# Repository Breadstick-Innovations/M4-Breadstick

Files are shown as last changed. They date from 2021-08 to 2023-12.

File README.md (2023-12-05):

# M4-Breadstick(retired) → [Raspberry Breadstick](https://github.com/Breadstick-Innovations/Raspberry-Breadstick)

## [Raspberry Breadstick Crowd Supply Campaign](https://www.crowdsupply.com/breadstick-innovations/raspberry-breadstick)
Be sure to [Subscribe!](https://www.crowdsupply.com/breadstick-innovations/raspberry-breadstick)

## [Hackaday IO](https://hackaday.io/project/180819-m4-breadstick)

## Adafruit Attribution
The M4-Breadstick is an adaptation of Adafruit's ItsyBitsy M4 Express; details about their board can be found [here](https://github.com/adafruit/Adafruit-ItsyBitsy-M4-Express-PCB).

## Design
### Goal
* Adapt a modern development board to a form factor which better compliments breadboard prototyping by reducing the number, length, and crossing of jumper-wires.

<insert more about the design shape and potential use cases>

### Examples
* Blink
  * [Files](Examples/1.%20Blink)
  * [YouTube Video](https://www.youtube.com/watch?v=jlcFvwoJDTA&list=PLvRCEIc8WROOZ6hJWuxPTIbie-fAAK2j3)
  
M4-Breadstick Blink Demo (https://www.youtube.com/watch?v=jlcFvwoJDTA&list=PLvRCEIc8WROOZ6hJWuxPTIbie-fAAK2j3)

* Buttons
  * [Files](Examples/7.%20Many%20Buttons)
  * [YouTube Video](https://www.youtube.com/watch?v=LMG715chEnE&list=PLvRCEIc8WROOZ6hJWuxPTIbie-fAAK2j3&index=6)
  
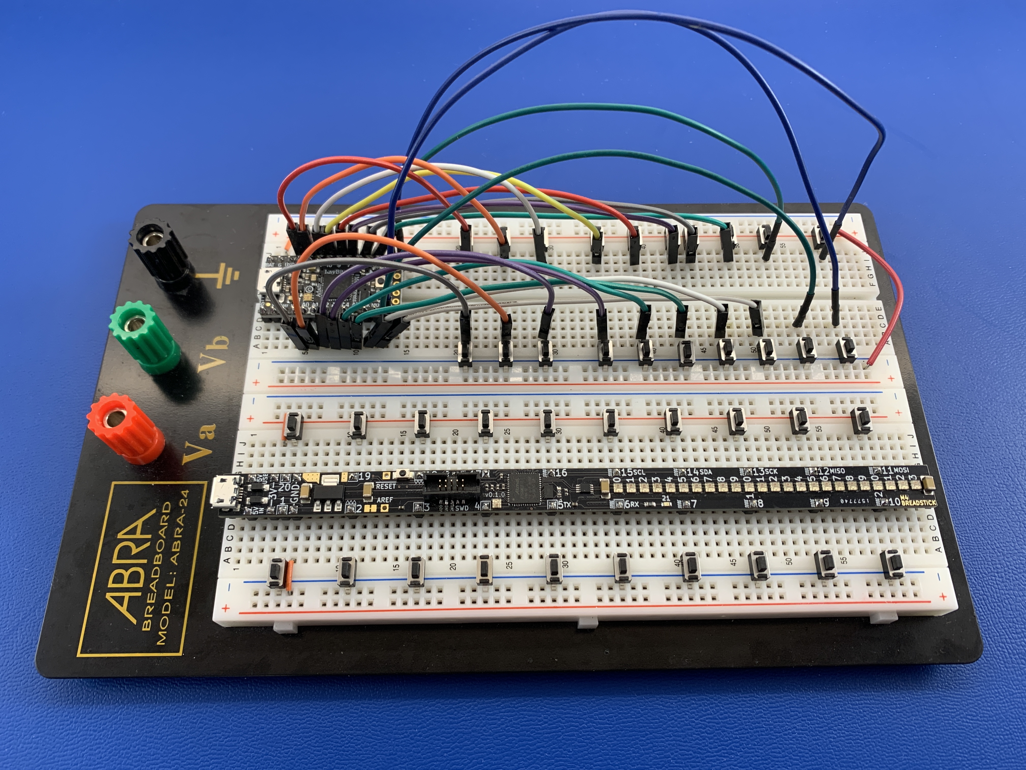
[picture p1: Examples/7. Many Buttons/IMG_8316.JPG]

M4-Breadstick Button Demo (https://www.youtube.com/watch?v=j13e2EzxIbE&list=PLvRCEIc8WROOZ6hJWuxPTIbie-fAAK2j3&index=4)
M4-Breadstick Many Buttons Demo (https://www.youtube.com/watch?v=LMG715chEnE&list=PLvRCEIc8WROOZ6hJWuxPTIbie-fAAK2j3&index=6)

* Potentiometers
  * [Files](Examples/3.%20Potentiometer/)
  * [YouTube Video](https://www.youtube.com/watch?v=UZgDf5CVg4E&list=PLvRCEIc8WROOZ6hJWuxPTIbie-fAAK2j3&index=3)
 
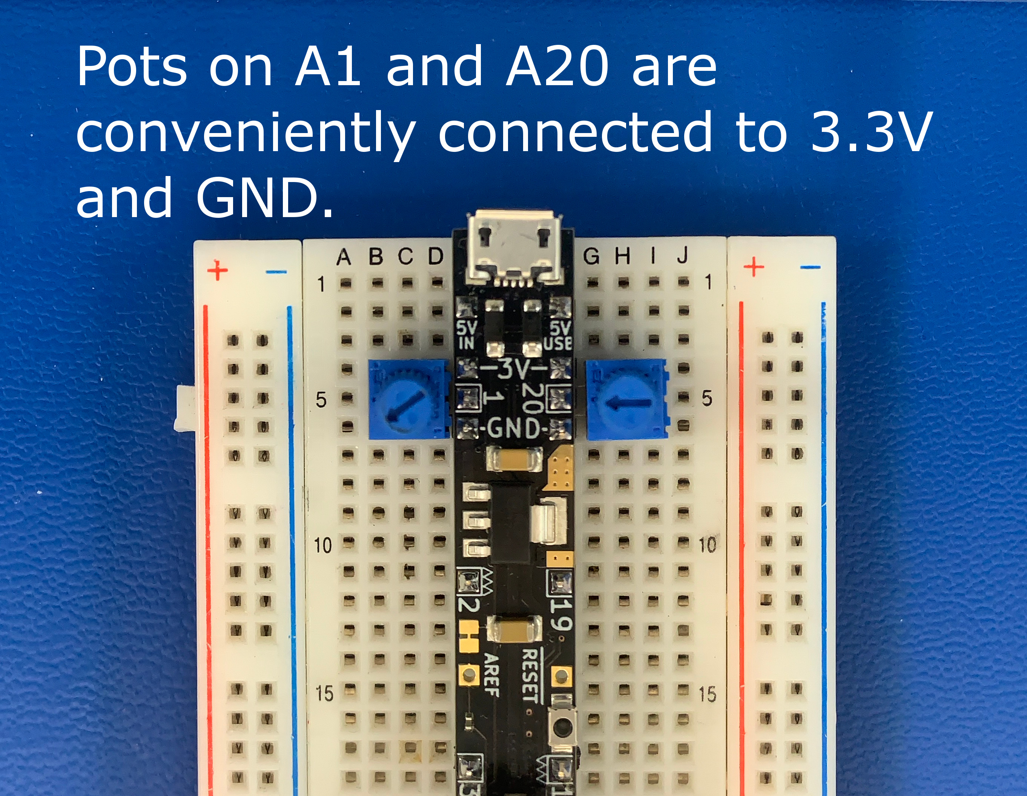
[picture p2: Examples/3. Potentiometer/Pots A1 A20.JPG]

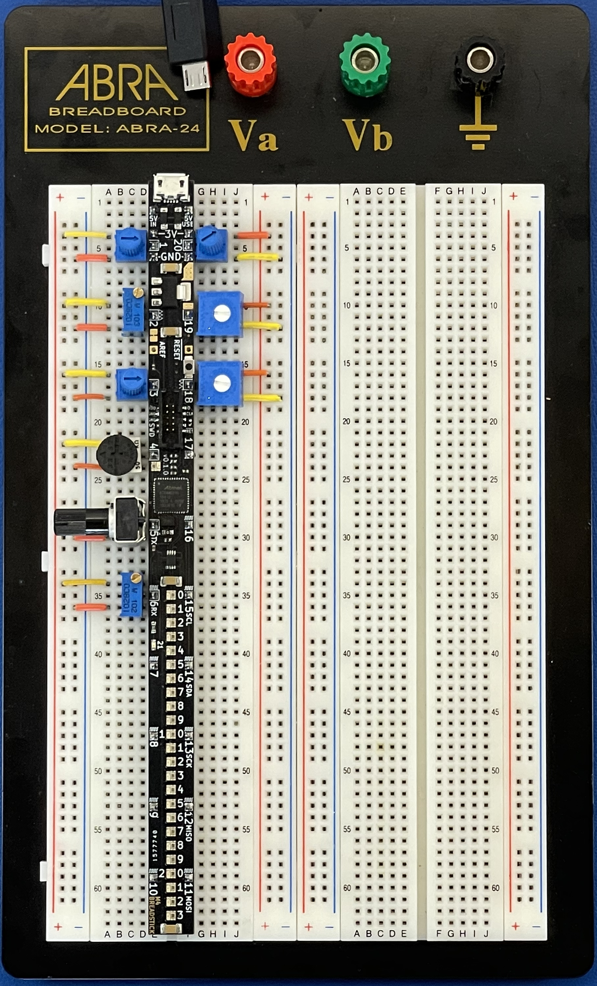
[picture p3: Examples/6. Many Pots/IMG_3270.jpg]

M4-Breadstick Potentiometer and Bar-Graph Demo (https://www.youtube.com/watch?v=UZgDf5CVg4E&list=PLvRCEIc8WROOZ6hJWuxPTIbie-fAAK2j3&index=3)

* Dual I2C Display
  * [Files](Examples/5.%20Dual%20I2C%20Display/)
  * [YouTube Video](https://www.youtube.com/watch?v=ZbwT2mgDPAQ&list=PLvRCEIc8WROOZ6hJWuxPTIbie-fAAK2j3&index=5)


M4-Breadstick Dual I2C Demo (https://www.youtube.com/watch?v=ZbwT2mgDPAQ&list=PLvRCEIc8WROOZ6hJWuxPTIbie-fAAK2j3&index=5)

* 24 Adressable RGB LED Strip (Dot-Star Compatible)
  * [Files](Examples/2.%20LED%20Strip)
  * [YouTube Video](https://www.youtube.com/watch?v=AKLR_5SblVk&list=PLvRCEIc8WROOZ6hJWuxPTIbie-fAAK2j3&index=2)

M4-Breadstick Dot-Star Compatible (Clock+Data) RGB LED Strip Demo (https://www.youtube.com/watch?v=AKLR_5SblVk&list=PLvRCEIc8WROOZ6hJWuxPTIbie-fAAK2j3&index=2)

* Motor Driver Demo
  * [Files](Examples/8.%20Motor%20Driver)
  * [YouTube Video](https://www.youtube.com/watch?v=vfRkdXOv09Y&list=PLvRCEIc8WROOZ6hJWuxPTIbie-fAAK2j3&index=7)

M4-Breadstick Motor Driver Demo (https://www.youtube.com/watch?v=vfRkdXOv09Y&list=PLvRCEIc8WROOZ6hJWuxPTIbie-fAAK2j3&index=7)

## Adafruit ItsyBitsy M4 Express PCB

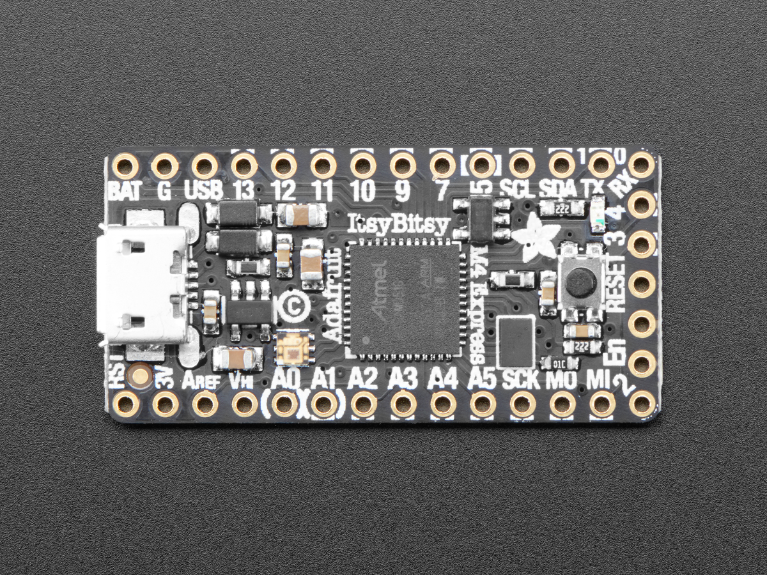
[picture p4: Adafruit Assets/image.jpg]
<a href="http://www.adafruit.com/products/3800"><br/>
Click here to purchase one from the Adafruit shop</a>

PCB files for the Adafruit ItsyBitsy M4 Express. PCB format is EagleCAD schematic and board layout

For more details, check out the product pages at
* https://www.adafruit.com/products/3800

### Description

What's smaller than a Feather but larger than a Trinket? It's an Adafruit ItsyBitsy M4 Express featuring the Microchip ATSAMD51! Small, powerful, with a ultra fast ATSAMD51 Cortex M4 processor running at 120 MHz - this microcontroller board is perfect when you want something very compact, with a ton of horsepower and a bunch of pins. This Itsy is like a bullet train, with it's 120MHz Cortex M4 with floating point support and 512KB Flash and 192KB RAM. Your code will zig and zag and zoom, and with a bunch of extra peripherals for support, this will for sure be your favorite new chipset.

ItsyBitsy M4 Express is only 1.4" long by 0.7" wide, but has 6 power pins, 23 digital GPIO pins (7 of which can be analog in, 2 x 1 MSPS analog out DACs, and 18 x PWM out). It's the same chip as the Adafruit Metro M4 but really really small. So it's great once you've finished up a prototype on a Metro M4 or (the upcoming) Feather M4, and want to make the project much smaller. It even comes with 2MB of SPI Flash built in, for data logging, file storage, or CircuitPython code.

The most exciting part of the ItsyBitsy M4 is that while you can use it with the Arduino IDE, we are shipping it with CircuitPython on board. When you plug it in, it will show up as a very small disk drive with main.py on it. Edit main.py with your favorite text editor to build your project using Python, the most popular programming language. No installs, IDE or compiler needed, so you can use it on any computer, even ChromeBooks or computers you can't install software on. When you're done, unplug the Itsy' and your code will go with you.

### License

Adafruit invests time and resources providing this open source design, please support Adafruit and open-source hardware by purchasing products from [Adafruit](https://www.adafruit.com)!

Designed by Limor Fried/Ladyada for Adafruit Industries.

Creative Commons Attribution/Share-Alike, all text above must be included in any redistribution. See license.txt for additional details.

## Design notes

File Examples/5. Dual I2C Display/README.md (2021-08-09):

## Dual I2C Display
### Description
Demonstrates the use of breadboard busses to facilitate power and I2C to multiple displays. Had to modify a config file and make a custom build of circuit python to enable a second display but it worked; firmware included above.
### Pins
The silkscreen shown in the video has a flaw, the labeled I2C pins did not actually support I2C functions. SERCOMs are very versatile; however, only SERCOMs x.0 serve as SDA and only x.1 can serve as SCL.

| Breadstick Pin | Function | Peripheral | Port |
| --- | --- | --- | --- |
| D7 | SDA | SERCOM 5.0 | PA23 |
| D8 | SCL | SERCOM 5.1 | PA22 |
| D13 | SDA | SERCOM 3.0 | PA17 |
| D16 | SCL | SERCOM 3.1 | PA16 |

### Video
M4-Breadstick Dual I2C Demo (https://www.youtube.com/watch?v=ZbwT2mgDPAQ)

https://www.youtube.com/watch?v=ZbwT2mgDPAQ

## OLED Display Mod
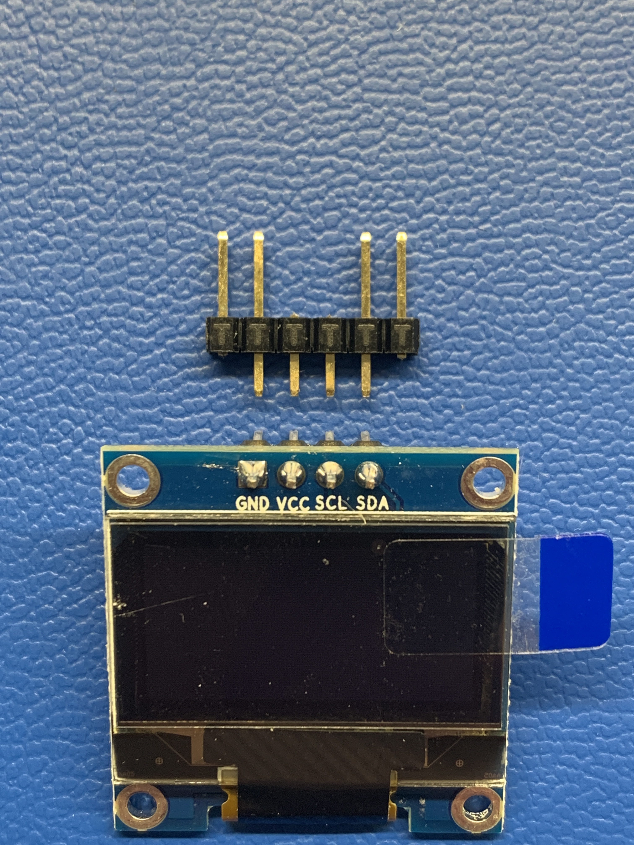
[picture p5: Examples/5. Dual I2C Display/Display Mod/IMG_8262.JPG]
<a href=""><br/>
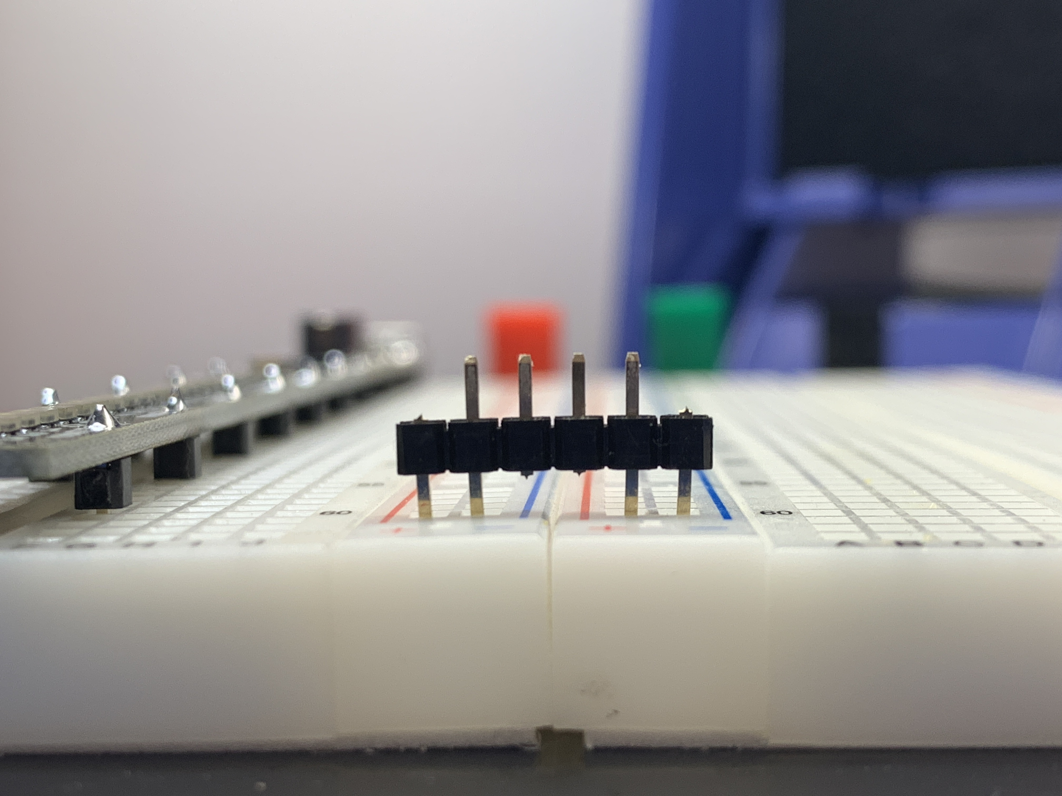
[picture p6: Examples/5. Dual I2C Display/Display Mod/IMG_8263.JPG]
<a href=""><br/>
<a href=""><br/>
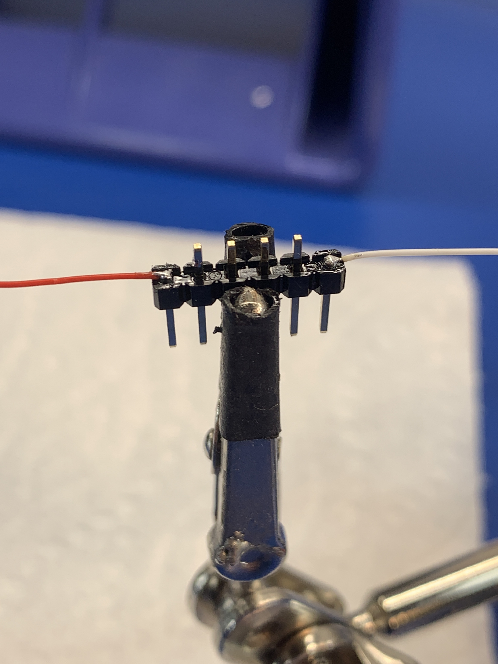
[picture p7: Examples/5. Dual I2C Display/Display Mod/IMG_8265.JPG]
<a href=""><br/>
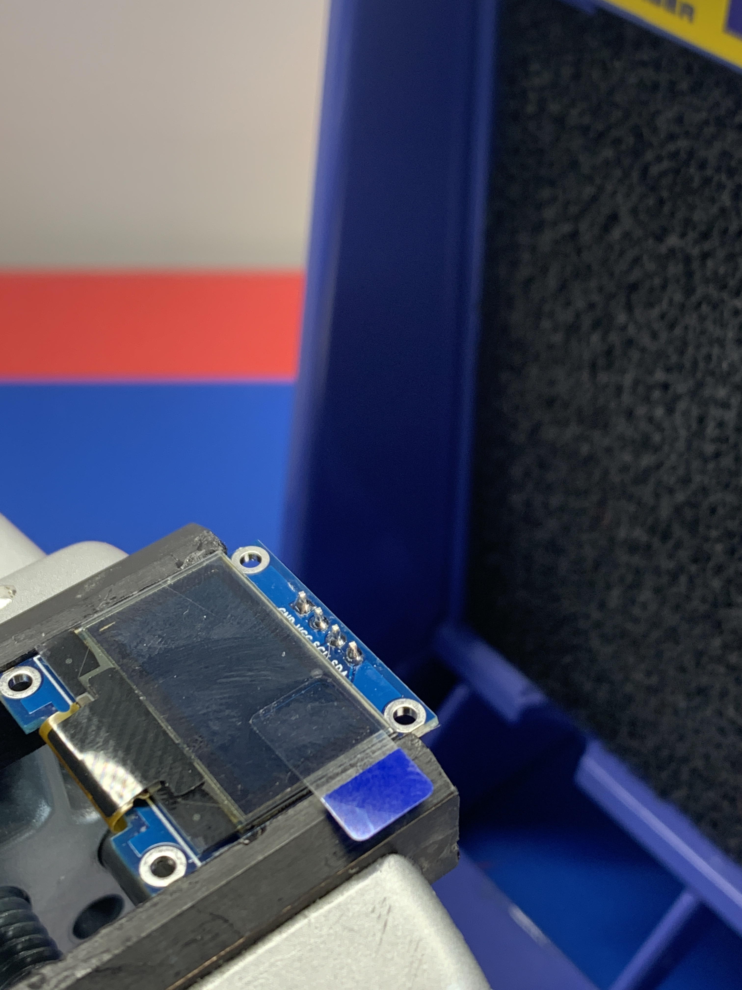
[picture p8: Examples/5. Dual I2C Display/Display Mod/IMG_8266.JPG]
<a href=""><br/>
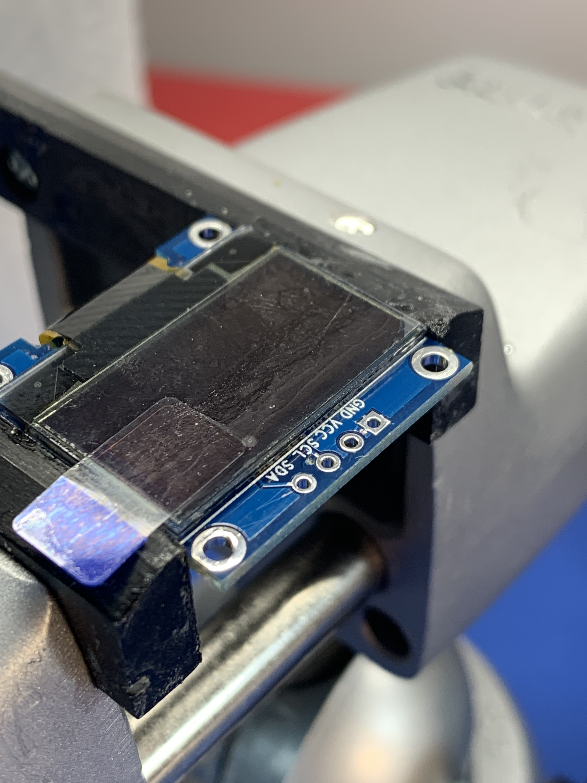
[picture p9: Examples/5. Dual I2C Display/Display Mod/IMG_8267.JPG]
<a href=""><br/>
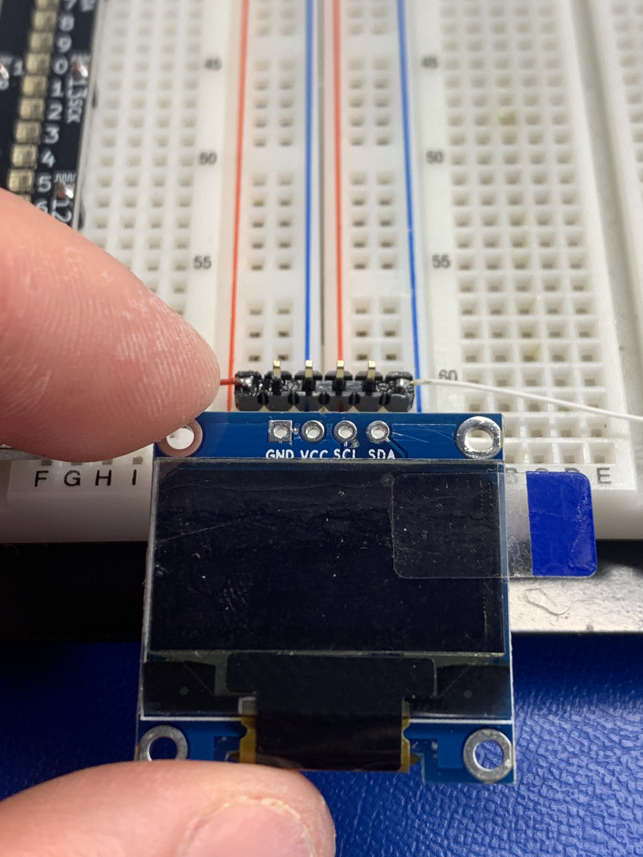
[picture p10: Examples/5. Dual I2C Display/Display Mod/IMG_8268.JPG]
<a href=""><br/>
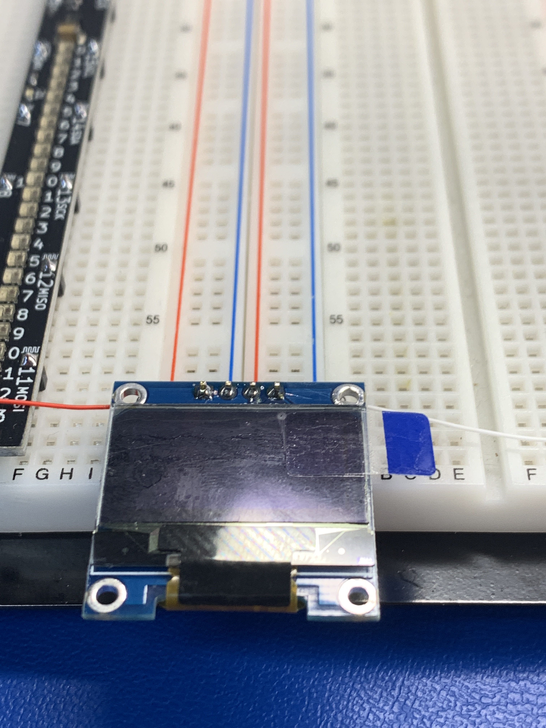
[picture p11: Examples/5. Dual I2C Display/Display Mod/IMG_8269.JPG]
<a href=""><br/>
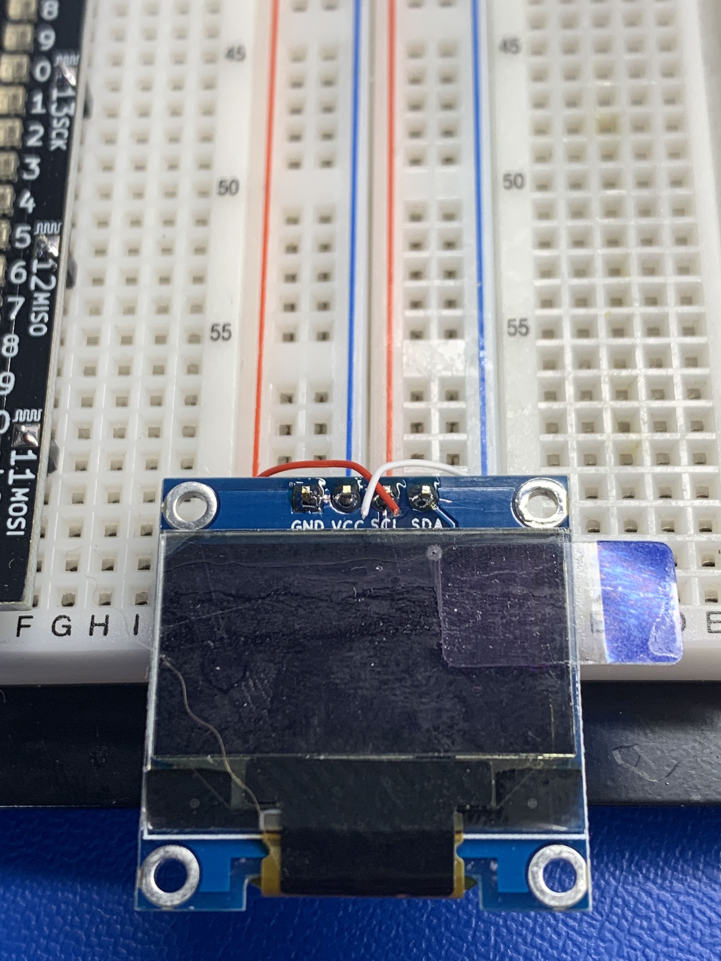
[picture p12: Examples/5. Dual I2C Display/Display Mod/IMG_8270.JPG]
<a href=""><br/>
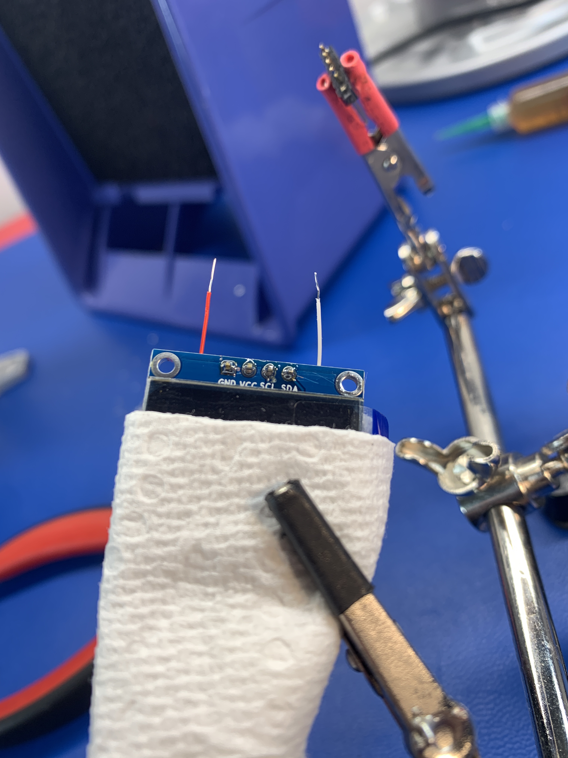
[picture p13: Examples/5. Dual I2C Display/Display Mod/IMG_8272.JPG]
<a href=""><br/>
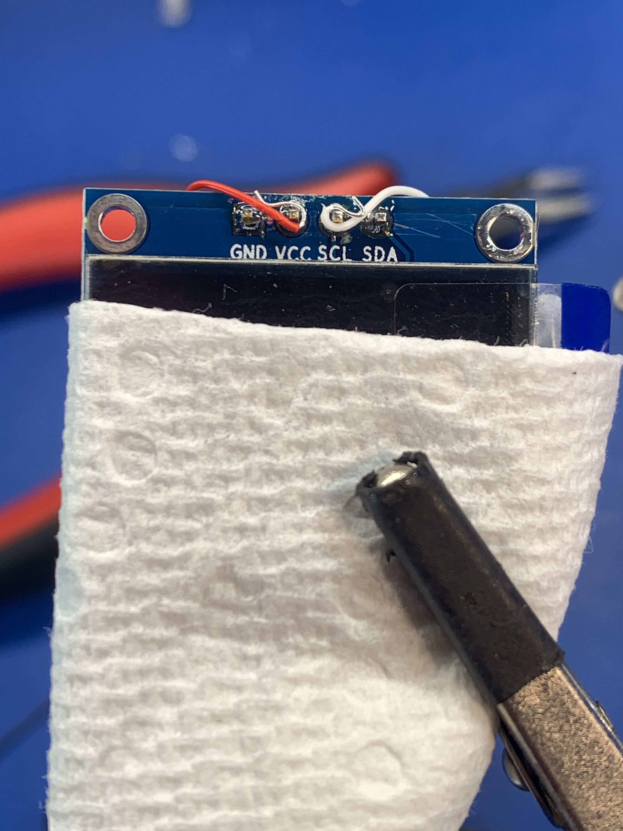
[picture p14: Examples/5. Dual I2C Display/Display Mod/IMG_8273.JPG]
<a href=""><br/>
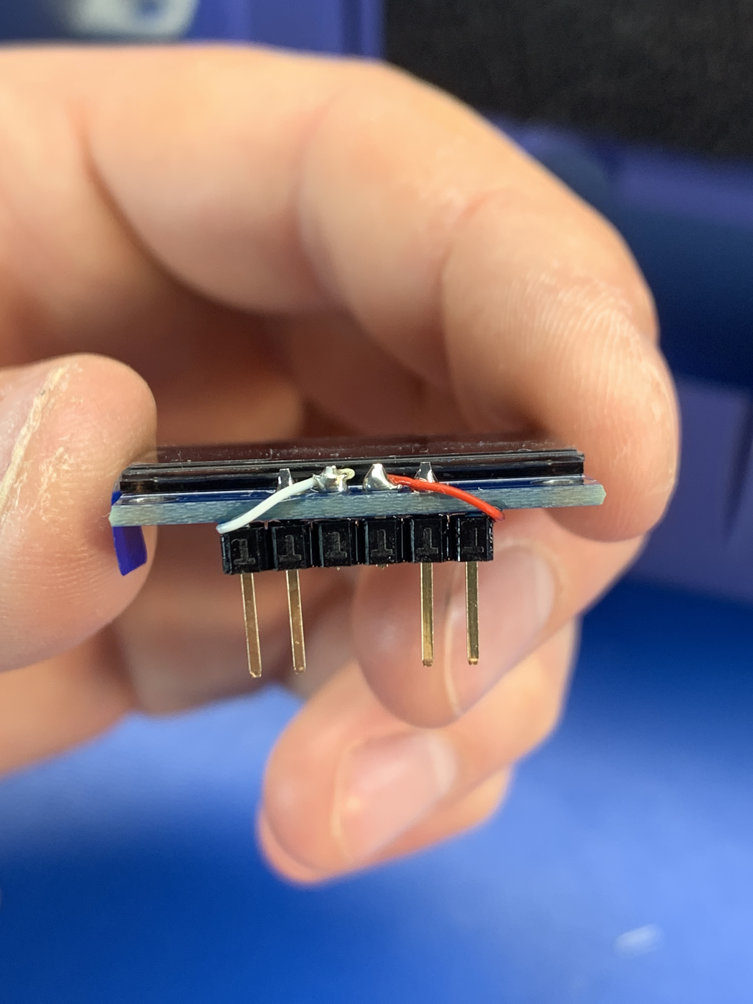
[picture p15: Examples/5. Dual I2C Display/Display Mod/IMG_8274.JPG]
<a href=""><br/>
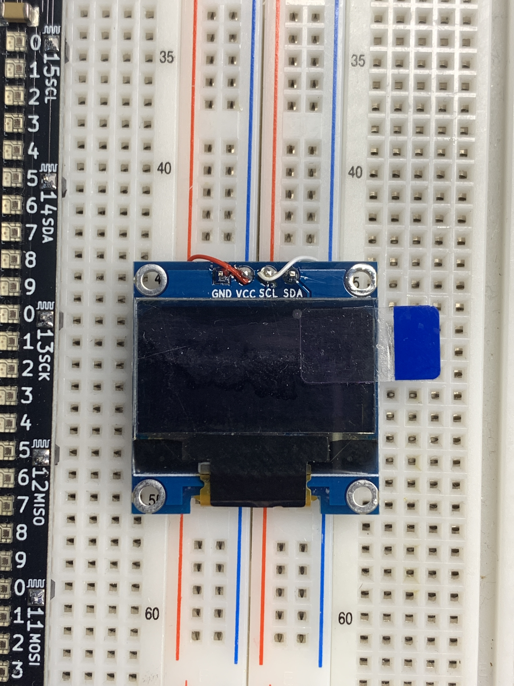
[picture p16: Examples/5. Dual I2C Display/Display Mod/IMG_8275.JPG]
<a href=""><br/>

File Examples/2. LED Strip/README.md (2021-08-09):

## LED Strip Demo
### Description
The LED strip consists of 24 LC8822-2020 adressable RGB LEDs that have dedicated Clock and Data pins and are compatible with Adafruit's DotStar library.
### Pins
LEDSTRIP_DATA

LEDSTRIP_CLOCK

### Video
M4-Breadstick Dot-Star Compatible (Clock+Data) RGB LED Strip Demo (https://www.youtube.com/watch?v=AKLR_5SblVk)

https://www.youtube.com/watch?v=AKLR_5SblVk

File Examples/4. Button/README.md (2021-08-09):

## Button Demo
### Description
Demonstrates the ease of connecting a button and mapping its input to an addressable RGB LED.

### Video
M4-Breadstick Button Demo (https://www.youtube.com/watch?v=j13e2EzxIbE)

https://www.youtube.com/watch?v=j13e2EzxIbE

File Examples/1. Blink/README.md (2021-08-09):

## Blink Demo
### Description
Blinks the red LED on pin D21.

### Video
M4-Breadstick Blink Demo (https://www.youtube.com/watch?v=jlcFvwoJDTA)

https://www.youtube.com/watch?v=jlcFvwoJDTA

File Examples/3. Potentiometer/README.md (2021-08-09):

## Potentiometer and Bar-Graph
### Description
Pins A1 and A20 are conveniently adjacent to 3.3V and Gnd, allowing a potentiometer to be connected without any additional wires. In this demo, the value read from the potentiometer is mapped to the RGB LED strip, to create a bar-graph.

### Video
M4-Breadstick Potentiometer and Bar-Graph Demo (https://www.youtube.com/watch?v=UZgDf5CVg4E)

https://www.youtube.com/watch?v=UZgDf5CVg4E

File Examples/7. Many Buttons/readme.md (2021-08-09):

## Many Button Demo
### Description
Demonstrates how quick and easy it is to connect many buttons to an M4-Breadstick.

### Video
M4-Breadstick Many Buttons Demo (https://www.youtube.com/watch?v=LMG715chEnE)

https://www.youtube.com/watch?v=LMG715chEnE

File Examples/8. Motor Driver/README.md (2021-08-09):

## Motor Driver Demo
### Description
Demonstrates the vertical support board concept using a motor driver.

### Video
M4-Breadstick Motor Driver Demo (https://www.youtube.com/watch?v=vfRkdXOv09Y)

https://www.youtube.com/watch?v=vfRkdXOv09Y

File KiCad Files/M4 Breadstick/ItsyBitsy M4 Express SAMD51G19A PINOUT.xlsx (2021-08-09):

 |  | ATSAMD51G19A
PWM | ItsyBitsy M4 | PIN | PAD | FUNCTIONS
2 | MOSI | 1 | PA00 | EIC/EXTINT[0] | SERCOM1/PAD[0] | TC2/WO[0]
1 | SCK | 2 | PA01 | EIC/EXTINT[1] | SERCOM1/PAD[1] | TC2/WO[1]
 | A0 | 3 | PA02 | EIC/EXTINT[2] | ADC0/AIN[0] | DAC/VOUT[0]
 | AREF | 4 | PA03 | EIC/EXTINT[3] | ANAREF/VREFA | ADC0/AIN[1] | X0/Y0
 |  | 5 | GNDANA
 |  | 6 | VDDANA
 | A2 | 7 | PB08 | EIC/EXTINT[8] | ADC0/AIN[2] | ADC1/AIN[0] | X1/Y1 | SERCOM4/PAD[0] | TC4/WO[0] | CCL/IN[8]
 | A3 | 8 | PB09 | EIC/EXTINT[9] | ADC0/AIN[3] | ADC1/AIN[1] | X2/Y2 | SERCOM4/PAD[1] | TC4/WO[1] | CCL/OUT[2]
2 | A4 | 9 | PA04 | EIC/EXTINT[4] | ANAREF/VREFB | ADC0/AIN[4] | AC/AIN[0] | X3/Y3 | SERCOM0/PAD[0] | TCO/WO[0] | CCL/[IN0]
 | A1 | 10 | PA05 | EIC/EXTINT[5] | ADC0/AIN[5] | AC/AIN[1] | DAC/VOUT[1] | SERCOM0/PAD[1] | TC0/WO[1] | CCL/IN[1]
2 | A5 | 11 | PA06 | EIC/EXTINT[6] | ANAREF/VREFC | ADC0/AIN[6] | AC/AIN[2] | X4/Y4 | SERCOM0/PAD[2] | TC1/WO[0] | SDHC0/SDCD | CCL/IN[2]
1 | D2 | 12 | PA07 | EIC/EXTINT[7] | ADC0/AIN[7] | AC/AIN[3] | X5/Y5 | SERCOM0/PAD[3] | TC1/WO[1] | SDHC0/SDWP | CCL/OUT[0]
 | QSPI/DATA | 13 | PA08 | EIC/NMI | ADC0/AIN[8] | ADC1/AIN[2] | X6/Y6 | SERCOM0/PAD[0] | SERCOM2/PAD[1] | TC0/WO[0] | TCC0/WO[0] | TCC1/WO[4] | QSPI/DATA[0] | SDHC0/SDCMD | I2S/MCK[0] | CCL/IN[3]
 | QSPI/DATA | 14 | PA09 | EIC/EXTINT[9] | ADC0/AIN[9] | ADC1/AIN[3] | X7/Y7 | SERCOM0/PAD[1] | SERCOM2/PAD[0] | TC0/WO[1] | TCC0/WO[1] | TCC1/WO[5] | QSPI/DATA[1] | SDHC0/SDDAT[0] | I2S/FS[0] | CCL/IN[4]
 | QSPI/DATA | 15 | PA10 | EIC/EXTINT[10] | ADC0/AIN[10] | X8/Y8 | SERCOM0/PAD[2] | SERCOM2/PAD[2] | TC1/WO[0] | TCC0/WO[2] | TCC1/WO[6] | QSPI/DATA[2] | SDHC0/SDDAT[1] | I2S/SCK[0] | GCLK/IO[4] | CCL/IN[5]
 | QSPI/DATA | 16 | PA11 | EIC/EXTINT[11] | ADC0/AIN[11] | X9/Y9 | SERCOM0/PAD[3] | SERCOM2/PAD[3] | TC1/WO[1] | TCC0/WO[3] | TCC1/WO[7] | QSPI/DATA[3] | SDHC0/SDDAT[2] | I2S/SDO | GCLK/IO[5] | CCL/OUT[1]
 |  | 17 | VDDIO
 |  | 18 | GNDANA
 | QSPI/SCK | 19 | PB10 | EIC/EXTINT[10] | SERCOM4/PAD[2] | TC5/WO[0] | TCC0/WO[4] | TCC1/WO[0] | QSPI/SCK | SDHC0/SDDAT[3] | I2S/SDI | GCLK/IO[4] | CCL/IN[11]
 | QSPI/CS | 20 | PB11 | EIC/EXTINT[11] | SERCOM4/PAD[3] | TC5/WO[1] | TCC0/WO[5] | TCC1/WO[1] | QSPI/CS | SDHC0/SDCK | I2S/FS[1] | GCLK/IO[5] | CCL/OUT[1]
1 | SDA | 21 | PA12 | EIC/EXTINT[12] | SERCOM2/PAD[0] | SERCOM4/PAD[1] | TC2/WO[0] | TCC0/WO[6] | TCC1/WO[2] | SDHC0/SDCD | PCC/DEN1 | GMAC/GRX[1] | AC/CMP[0]
1 | SCL | 22 | PA13 | EIC/EXTINT[13] | SERCOM2/PAD[1] | SERCOM4/PAD[0] | TC2/WO[1] | TCC0/WO[7] | TCC1/WO[3] | SDHC0/SDWP | PCC/DEN2 | GMAC/GRX[0] | AC/CMP[1]
1 | D4 | 23 | PA14 | EIC/EXTINT[14] | SERCOM2/PAD[2] | SERCOM4/PAD[2] | TC2/WO[0] | TCC2/WO[0] | TCC1/WO[2] | PCC/CLK | GMAC/GTXCK | GLCK/IO[0]
1 | D5 | 24 | PA15 | EIC/EXTINT[15] | SERCOM2/PAD[3] | SERCOM45/PAD[3] | TC3/WO[1] | TCC2/WO[1] | TCC1/WO[3] | GMAC/GRXER | GCLK/IO[1]
1 | D0/RX | 25 | PA16 | EIC/EXTINT[0] | X10/Y10 | SERCOM1/PAD[0] | SERCOM3/PAD[1] | TC2/WO[0] | TCC1/WO[0] | TCC0/WO[4] | PCC/DATA[0] | GMAC/GCRS/GRXDV(6) | GCLK/IO[2] | CCL/IN[0]
1 | D1/TX | 26 | PA17 | EIC/EXTINT[1] | X11/Y11 | SERCOM1/PAD[1] | SERCOM3/PAD[0] | TC2/WO[1] | TCC1/WO[1] | TCC0/WO[5] | PCC/DATA[1] | GMAC/GTXEN | GCLK/IO[3] | CCL/IN[1]
1 | D7 | 27 | PA18 | EIC/EXTINT[2] | X12/Y12 | SERCOM1/PAD[2] | SERCOM3/PAD[2] | TC3/WO[0] | TCC1/WO[2] | TCC0/WO[6] | PCC/DATA[2] | GMAC/GTX[0] | AC/CMP[0] | CCL/IN[2]
1 | D9 | 28 | PA19 | EIC/EXTINT[3] | X13/Y13 | SERCOM1/PAD[3] | SERCOM3/PAD[3] | TC3/WO[1] | TCC1/WO[3] | TCC0/WO[7] | PCC/DATA[3] | GMAC/GTX[1] | AC/CMP[1] | CCL/OUT[0]
1 | D10 | 29 | PA20 | EIC/EXTINT[4] | X14/Y14 | SERCOM5/PAD[2] | SERCOM3/PAD[2] | TC7/WO[0] | TCC1/WO[4] | TCC0/WO[0] | SDHC1/SDCMD | I2S/FS[0] | PCC/DATA[4] | GMAC/GMDC
1 | D11 | 30 | PA21 | EIC/EXTINT[5] | X15/Y15 | SERCOM5/PAD[3] | SERCOM3/PAD[3] | TC7/WO[1] | TCC1/WO[5] | TCC0/WO[1] | SDHC1/SDCK | I2S/SDO | PCC/DATA[5] | GMCA/GMDIO
1 | D13 | 31 | PA22 | EIC/EXTINT[6] | X16/Y16 | SERCOM3/PAD[0] | SERCOM5/PAD[1] | TC4/WO[0] | TCC1/WO[6] | TCC0/WO[2] | CAN0/TX | I2S/SDI | PCC/DATA[6] | CCL/IN[6]
1 | D12 | 32 | PA23 | EIC/EXTINT[7] | X17/Y17 | SERCOM3/PAD[1] | SERCOM5/PAD[0] | TC4/WO[1] | TCC1/WO[7] | TCC0/WO[3] | USB/SOF_1KHZ | CAN0/RX | I2S/FS[1] | PCC/DATA[7] | CCL/IN[7]
 | USB/D- | 33 | PA24 | EIC/EXTINT[8] | SERCOM3/PAD[2] | SERCOM5/PAD[2] | TC5/WO[0] | TCC2/WO[2] | PDEC/PDEC[0] | USB/DM | CAN0/TX | CCL/IN[8]
 | USB/D+ | 34 | PA25 | EIC/EXTINT[9] | SERCOM3/PAD[3] | SERCOM5/PAD[3] | TC5/WO[1] | PDEC/PDEC[1] | USB/DP | CAN0/RX | CCL/OUT[2]
 |  | 35 | GNDANA
 |  | 36 | VDDIO
 | D3 | 37 | PB22 | EIC/EXTINT[6] | SERCOM1/PAD[2] | SERCOM5/PAD[2] | TC7/WO[0] | PDEC/PDEC[2] | USB/SOF_1KHZ | GCLK/IO[0] | CCL/IN[0]
 | MISO | 38 | PB23 | EIC/EXTINT[7] | SERCOM1/PAD[3] | SERCOM5/PAD[3] | TC7/WO[1] | PDEC/PDEC[0] | GCLK/IO[1] | CCL/OUT[0]
 |  | 39 | PA29 | EIC/EXTINT[11] | X18/Y18 | GCLK/IO[1]
 | RESET | 40 | RESETN
 |  | 41 | VDDCORE
 |  | 42 | GNDANA
 |  | 43 | VSW
 |  | 44 | VDDIO
 | SWCLK | 45 | PA30 | EIC/EXTINT[14] | X19/Y19 | SERCOM7/PAD[2] | SERCOM1/PAD[2] | TC6/WO[0] | TCC2/WO[0] | CORTEX_CM4/SWCLK | GCLK/IO[0] | CCL/IN[3]
 | SWDIO | 46 | PA31 | EIC/EXTINT[15] | SERCOM7/PAD[3] | SERCOM1/PAD[3] | TC6/WO[1] | TCC2/WO[1] | CORTEX_CM4/SWDIO | CCL/OUT[1]
 | APA102/SCK | 47 | PB02 | EIC/EXTINT[2] | ADC0/AIN[14] | X20/Y20 | SERCOM5/PAD[0] | TC6/WO[0] | TCC2/WO[2] | CCL/OUT[0]
 | APA102/MOSI | 48 | PB03 | EIC/EXTINT[3] | ADC0/AIN[15] | X21/Y21 | SERCOM5/PAD[1] | TC6/WO[1]

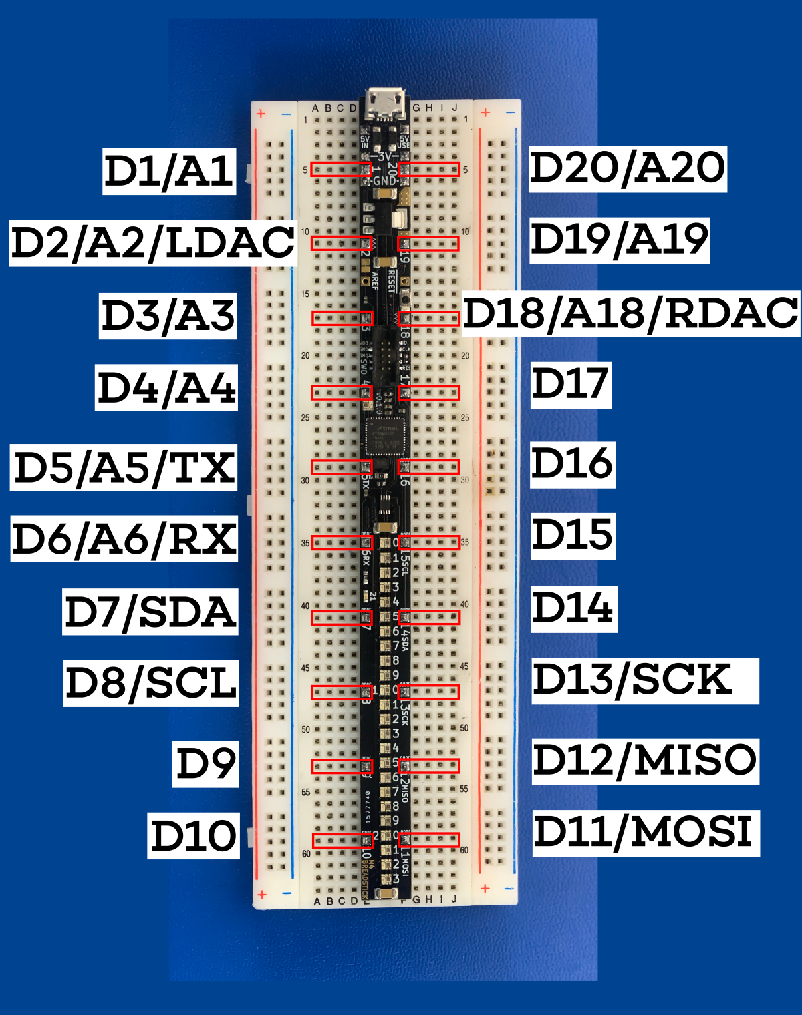
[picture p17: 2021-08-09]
Documentation/M4 Breadstick Pinout.png

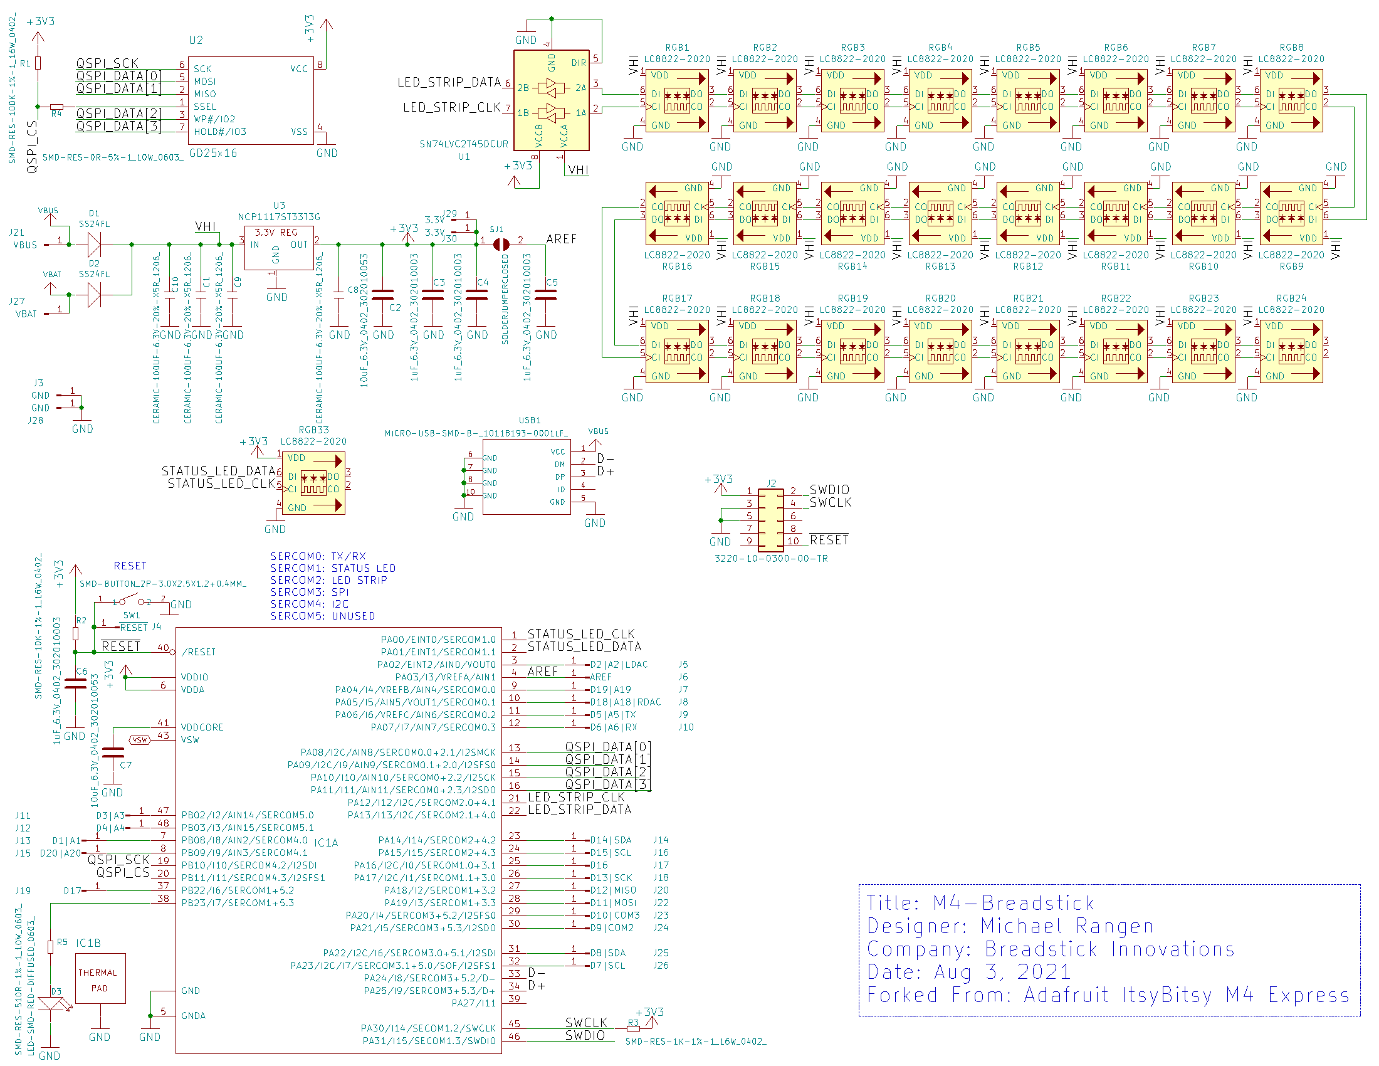
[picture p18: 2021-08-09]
Documentation/M4 Breadstick Schematic.png

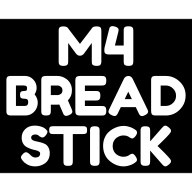
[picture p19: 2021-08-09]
KiCad Files/M4 Breadstick/.svg2shenzhen-cache/images/F.SilkS_g871.png

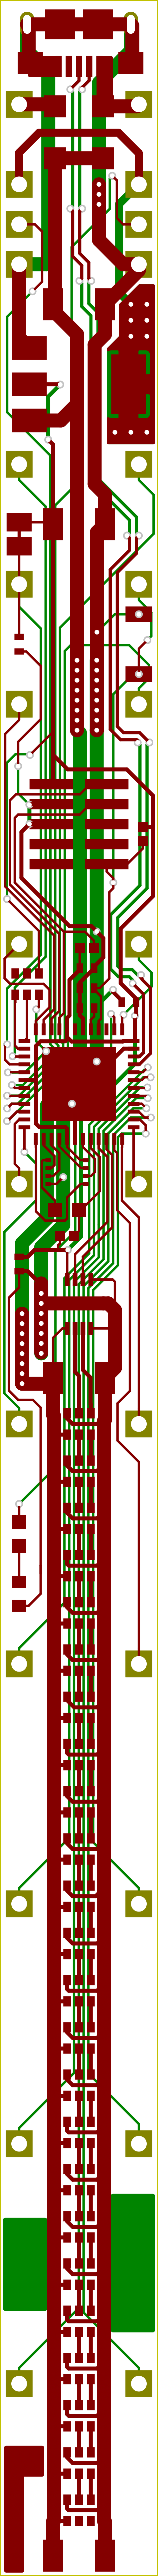
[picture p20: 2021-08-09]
Documentation/M4 Breadstick PCB.png

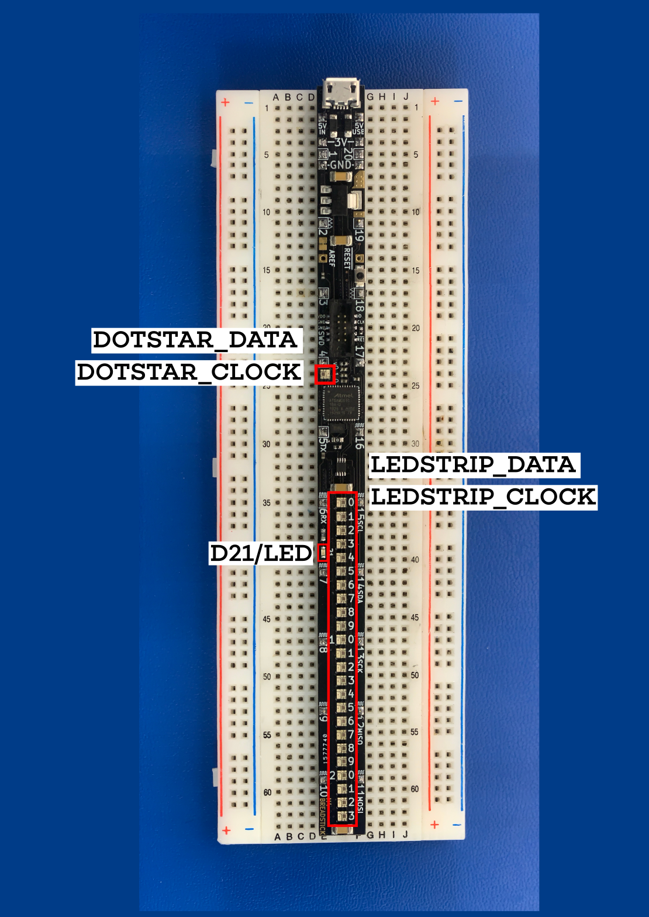
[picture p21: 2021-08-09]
Documentation/M4 Breadstick LEDs.png

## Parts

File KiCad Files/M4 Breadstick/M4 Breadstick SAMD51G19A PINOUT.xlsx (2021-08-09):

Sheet: Sheet1
 |  |  |  |  | ATSAMD51G19A
DAC | ADC | PWM | Breakout | ItsyBitsy M4 | M4 Breadstick | PIN | PAD | FUNCTIONS
 |  | 2 |  | MOSI | APA102/SCK | 1 | PA00 | EIC/EXTINT[0] | SERCOM1/PAD[0] | TC2/WO[0]
 |  | 1 |  | SCK | APA102/MOSI | 2 | PA01 | EIC/EXTINT[1] | SERCOM1/PAD[1] | TC2/WO[1]
1 | 1 |  | 1 | A0 | DAC0 | 3 | PA02 | EIC/EXTINT[2] | ADC0/AIN[0] | DAC/VOUT[0]
 |  |  | 2 | AREF | AREF | 4 | PA03 | EIC/EXTINT[3] | ANAREF/VREFA | ADC0/AIN[1] | X0/Y0
 |  |  |  |  |  | 5 | GNDANA
 |  |  |  |  |  | 6 | VDDANA
 |  |  | 1 | A2 | I2C | 7 | PB08 | EIC/EXTINT[8] | ADC0/AIN[2] | ADC1/AIN[0] | X1/Y1 | SERCOM4/PAD[0] | TC4/WO[0] | CCL/IN[8]
 |  |  | 1 | A3 | I2C | 8 | PB09 | EIC/EXTINT[9] | ADC0/AIN[3] | ADC1/AIN[1] | X2/Y2 | SERCOM4/PAD[1] | TC4/WO[1] | CCL/OUT[2]
 | 1 | 2 | 1 | A4 | ADC | 9 | PA04 | EIC/EXTINT[4] | ANAREF/VREFB | ADC0/AIN[4] | AC/AIN[0] | X3/Y3 | SERCOM0/PAD[0] | TCO/WO[0] | CCL/[IN0]
1 | 1 |  | 1 | A1 | DAC1 | 10 | PA05 | EIC/EXTINT[5] | ADC0/AIN[5] | AC/AIN[1] | DAC/VOUT[1] | SERCOM0/PAD[1] | TC0/WO[1] | CCL/IN[1]
 | 1 | 2 | 1 | A5 | TX/RX | 11 | PA06 | EIC/EXTINT[6] | ANAREF/VREFC | ADC0/AIN[6] | AC/AIN[2] | X4/Y4 | SERCOM0/PAD[2] | TC1/WO[0] | SDHC0/SDCD | CCL/IN[2]
 | 1 | 1 | 1 | D2 | TX/RX | 12 | PA07 | EIC/EXTINT[7] | ADC0/AIN[7] | AC/AIN[3] | X5/Y5 | SERCOM0/PAD[3] | TC1/WO[1] | SDHC0/SDWP | CCL/OUT[0]
 |  |  |  | QSPI/DATA | QSPI/DATA | 13 | PA08 | EIC/NMI | ADC0/AIN[8] | ADC1/AIN[2] | X6/Y6 | SERCOM0/PAD[0] | SERCOM2/PAD[1] | TC0/WO[0] | TCC0/WO[0] | TCC1/WO[4] | QSPI/DATA[0] | SDHC0/SDCMD | I2S/MCK[0] | CCL/IN[3]
 |  |  |  | QSPI/DATA | QSPI/DATA | 14 | PA09 | EIC/EXTINT[9] | ADC0/AIN[9] | ADC1/AIN[3] | X7/Y7 | SERCOM0/PAD[1] | SERCOM2/PAD[0] | TC0/WO[1] | TCC0/WO[1] | TCC1/WO[5] | QSPI/DATA[1] | SDHC0/SDDAT[0] | I2S/FS[0] | CCL/IN[4]
 |  |  |  | QSPI/DATA | QSPI/DATA | 15 | PA10 | EIC/EXTINT[10] | ADC0/AIN[10] | X8/Y8 | SERCOM0/PAD[2] | SERCOM2/PAD[2] | TC1/WO[0] | TCC0/WO[2] | TCC1/WO[6] | QSPI/DATA[2] | SDHC0/SDDAT[1] | I2S/SCK[0] | GCLK/IO[4] | CCL/IN[5]
 |  |  |  | QSPI/DATA | QSPI/DATA | 16 | PA11 | EIC/EXTINT[11] | ADC0/AIN[11] | X9/Y9 | SERCOM0/PAD[3] | SERCOM2/PAD[3] | TC1/WO[1] | TCC0/WO[3] | TCC1/WO[7] | QSPI/DATA[3] | SDHC0/SDDAT[2] | I2S/SDO | GCLK/IO[5] | CCL/OUT[1]
 |  |  |  |  |  | 17 | VDDIO
 |  |  |  |  |  | 18 | GNDANA
 |  |  |  | QSPI/SCK | QSPI/SCK | 19 | PB10 | EIC/EXTINT[10] | SERCOM4/PAD[2] | TC5/WO[0] | TCC0/WO[4] | TCC1/WO[0] | QSPI/SCK | SDHC0/SDDAT[3] | I2S/SDI | GCLK/IO[4] | CCL/IN[11]
 |  |  |  | QSPI/CS | QSPI/CS | 20 | PB11 | EIC/EXTINT[11] | SERCOM4/PAD[3] | TC5/WO[1] | TCC0/WO[5] | TCC1/WO[1] | QSPI/CS | SDHC0/SDCK | I2S/FS[1] | GCLK/IO[5] | CCL/OUT[1]
 |  | 1 |  | SDA | MYAPA102 | 21 | PA12 |  | SERCOM2/PAD[0] | SERCOM4/PAD[1] | TC2/WO[0] | TCC0/WO[6] | TCC1/WO[2] | SDHC0/SDCD | PCC/DEN1 | GMAC/GRX[1] | AC/CMP[0]
 |  | 1 |  | SCL | MYAPA102 | 22 | PA13 | EIC/EXTINT[13] | SERCOM2/PAD[1] | SERCOM4/PAD[0] | TC2/WO[1] | TCC0/WO[7] | TCC1/WO[3] | SDHC0/SDWP | PCC/DEN2 | GMAC/GRX[0] | AC/CMP[1]
 |  | 1 | 1 | D4 | D | 23 | PA14 | EIC/EXTINT[14] | SERCOM2/PAD[2] | SERCOM4/PAD[2] | TC2/WO[0] | TCC2/WO[0] | TCC1/WO[2] | PCC/CLK | GMAC/GTXCK | GLCK/IO[0]
 |  | 1 | 1 | D5 | D | 24 | PA15 | EIC/EXTINT[15] | SERCOM2/PAD[3] | SERCOM45/PAD[3] | TC3/WO[1] | TCC2/WO[1] | TCC1/WO[3] | GMAC/GRXER | GCLK/IO[1]
 |  | 1 | 1 | D0/RX | D | 25 | PA16 | EIC/EXTINT[0] | X10/Y10 | SERCOM1/PAD[0] | SERCOM3/PAD[1] | TC2/WO[0] | TCC1/WO[0] | TCC0/WO[4] | PCC/DATA[0] | GMAC/GCRS/GRXDV(6) | GCLK/IO[2] | CCL/IN[0]
 |  | 1 | 1 | D1/TX | SPI | 26 | PA17 | EIC/EXTINT[1] | X11/Y11 | SERCOM1/PAD[1] | SERCOM3/PAD[0] | TC2/WO[1] | TCC1/WO[1] | TCC0/WO[5] | PCC/DATA[1] | GMAC/GTXEN | GCLK/IO[3] | CCL/IN[1]
 |  | 1 | 1 | D7 | SPI | 27 | PA18 | EIC/EXTINT[2] | X12/Y12 | SERCOM1/PAD[2] | SERCOM3/PAD[2] | TC3/WO[0] | TCC1/WO[2] | TCC0/WO[6] | PCC/DATA[2] | GMAC/GTX[0] | AC/CMP[0] | CCL/IN[2]
 |  | 1 | 1 | D9 | SPI | 28 | PA19 | EIC/EXTINT[3] | X13/Y13 | SERCOM1/PAD[3] | SERCOM3/PAD[3] | TC3/WO[1] | TCC1/WO[3] | TCC0/WO[7] | PCC/DATA[3] | GMAC/GTX[1] | AC/CMP[1] | CCL/OUT[0]
 |  | 1 | 1 | D10 | D | 29 | PA20 | EIC/EXTINT[4] | X14/Y14 | SERCOM5/PAD[2] | SERCOM3/PAD[2] | TC7/WO[0] | TCC1/WO[4] | TCC0/WO[0] | SDHC1/SDCMD | I2S/FS[0] | PCC/DATA[4] | GMAC/GMDC
 |  | 1 | 1 | D11 | D | 30 | PA21 | EIC/EXTINT[5] | X15/Y15 | SERCOM5/PAD[3] | SERCOM3/PAD[3] | TC7/WO[1] | TCC1/WO[5] | TCC0/WO[1] | SDHC1/SDCK | I2S/SDO | PCC/DATA[5] | GMCA/GMDIO
cc |  | 1 | 1 | D13 | D | 31 | PA22 | EIC/EXTINT[6] | X16/Y16 | SERCOM3/PAD[0] | SERCOM5/PAD[1] | TC4/WO[0] | TCC1/WO[6] | TCC0/WO[2] | CAN0/TX | I2S/SDI | PCC/DATA[6] | CCL/IN[6]
 |  | 1 | 1 | D12 | D | 32 | PA23 | EIC/EXTINT[7] | X17/Y17 | SERCOM3/PAD[1] | SERCOM5/PAD[0] | TC4/WO[1] | TCC1/WO[7] | TCC0/WO[3] | USB/SOF_1KHZ | CAN0/RX | I2S/FS[1] | PCC/DATA[7] | CCL/IN[7]
 |  |  |  | USB/D- | USB/D- | 33 | PA24 | EIC/EXTINT[8] | SERCOM3/PAD[2] | SERCOM5/PAD[2] | TC5/WO[0] | TCC2/WO[2] | PDEC/PDEC[0] | USB/DM | CAN0/TX | CCL/IN[8]
 |  |  |  | USB/D+ | USB/D+ | 34 | PA25 | EIC/EXTINT[9] | SERCOM3/PAD[3] | SERCOM5/PAD[3] | TC5/WO[1] | PDEC/PDEC[1] | USB/DP | CAN0/RX | CCL/OUT[2]
 |  |  |  |  |  | 35 | GNDANA
 |  |  |  |  |  | 36 | VDDIO
 |  |  | 1 | D3 | D | 37 | PB22 | EIC/EXTINT[6] | SERCOM1/PAD[2] | SERCOM5/PAD[2] | TC7/WO[0] | PDEC/PDEC[2] | USB/SOF_1KHZ | GCLK/IO[0] | CCL/IN[0]
 |  |  | 1 | MISO | D | 38 | PB23 | EIC/EXTINT[7] | SERCOM1/PAD[3] | SERCOM5/PAD[3] | TC7/WO[1] | PDEC/PDEC[0] | GCLK/IO[1] | CCL/OUT[0]
 |  |  | 1 |  | D | 39 | PA27 | EIC/EXTINT[11] | X18/Y18 | GCLK/IO[1]
 |  |  | 2 | RESET | RESET | 40 | RESETN
 |  |  |  |  |  | 41 | VDDCORE
 |  |  |  |  |  | 42 | GNDANA
 |  |  |  |  |  | 43 | VSW
 |  |  |  |  |  | 44 | VDDIO
 |  |  |  | SWCLK | SWCLK | 45 | PA30 | EIC/EXTINT[14] | X19/Y19 | SERCOM7/PAD[2] | SERCOM1/PAD[2] | TC6/WO[0] | TCC2/WO[0] | CORTEX_CM4/SWCLK | GCLK/IO[0] | CCL/IN[3]
 |  |  |  | SWDIO | SWDIO | 46 | PA31 | EIC/EXTINT[15] | SERCOM7/PAD[3] | SERCOM1/PAD[3] | TC6/WO[1] | TCC2/WO[1] | CORTEX_CM4/SWDIO | CCL/OUT[1]
 | 1 |  | 1 | APA102/SCK | ADC | 47 | PB02 | EIC/EXTINT[2] | ADC0/AIN[14] | X20/Y20 | SERCOM5/PAD[0] | TC6/WO[0] | TCC2/WO[2] | CCL/OUT[0]
 | 1 |  | 1 | APA102/MOSI | ADC | 48 | PB03 | EIC/EXTINT[3] | ADC0/AIN[15] | X21/Y21 | SERCOM5/PAD[1] | TC6/WO[1]

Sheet: Sheet2
Name | Serial | D | Pin | Pin | D | Serial | Name
A0 |  | D1 | 7 | 8 | D20 |  | A1
A2 |  | D2 | 3 | 9 | D19 |  | A3
A4 |  | D3 | 47 | 10 | D18 |  | A5
A6 |  | D4 | 48 | 37 | D17 | 5.2 | D17
TX | 0.2 | D5 | 11 | 25 | D16 | 3.1 | D16
RX | 0.3 | D6 | 12 | 24 | D15 | 4.3 | SCL
COM0 | 5.0 | D7 | 32 | 23 | D14 | 4.2 | SDA
COM1 | 5.1 | D8 | 31 | 26 | D13 | 3.0 | SCK
COM2 | 5.3 | D9 | 30 | 27 | D12 | 3.2 | MISO
COM3 | 5.2 | D10 | 29 | 28 | D11 | 3.3 | MOSI
 |  |  |  | L | LED_BUILTIN

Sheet: Sheet3
ITSYBITSY M4 PIN | SAMD51 PIN | BREADSTICK PIN | FUNCTIONS
 |  |  | ADC | DAC | PWM
A2 | 7 | 1 | 2
A0 | 3 | 2 | 2 | 2
DOTSTAR_CLK | 47 | 3 | 2
DOTSTAR_DATA | 48 | 4 | 2
A5 | 11 | 5 | 2 |  | 3
D2 | 12 | 6 | 2 |  | 2
D12 | 32 | 7 |  |  | 2
D13 | 31 | 8 |  |  | 2
D11 | 30 | 9 |  |  | 2
D10 | 29 | 10 |  |  | 2
D9 | 28 | 11 |  |  | 2
D7 | 27 | 12 |  |  | 2
TX_D1 | 26 | 13 |  |  | 2
D4 | 23 | 14 |  |  | 2
D5 | 24 | 15 |  |  | 2
RX_D0 | 25 | 16 |  |  | 2
D3 | 37 | 17
A1 | 10 | 18 | 2 | 2
A4 | 9 | 19 | 2 |  | 3
A3 | 8 | 20 | 2
MISO | 38 | 21
 |  |  | 1 | Assumed
 |  |  | 2 | Confirmed
 |  |  | 3 | Works but not in CircuitPython

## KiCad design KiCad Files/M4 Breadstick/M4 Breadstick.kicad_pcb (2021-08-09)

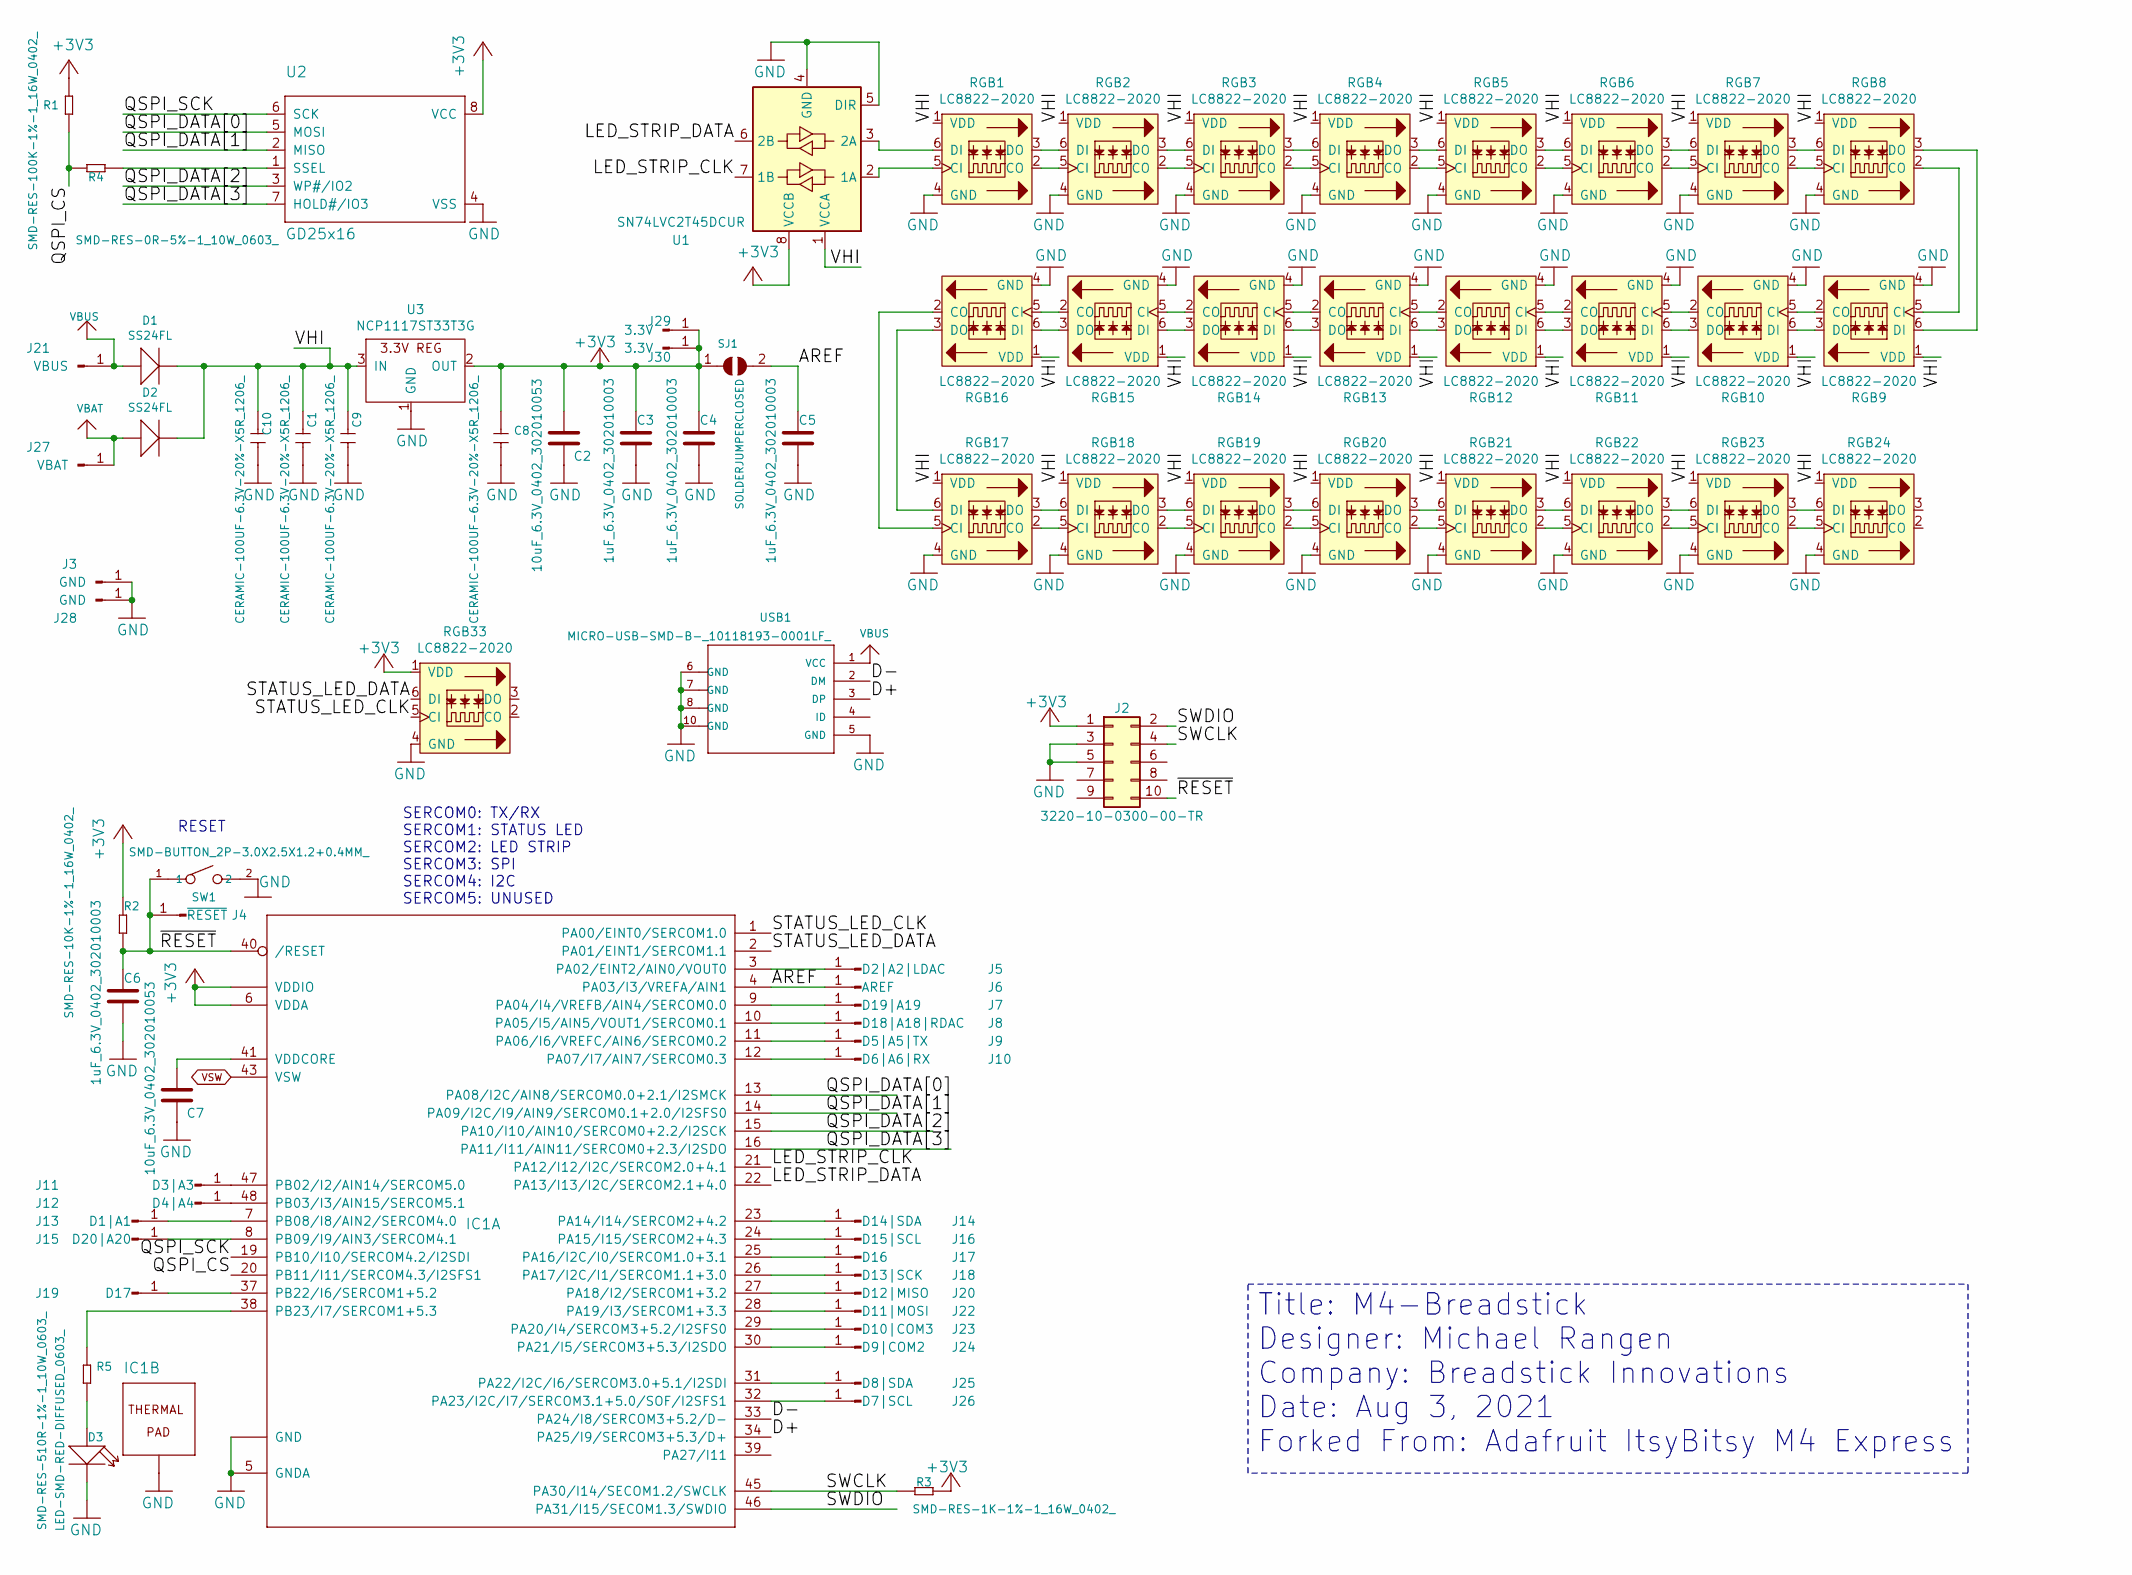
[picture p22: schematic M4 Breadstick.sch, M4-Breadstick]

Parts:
C1, C8, C9, C10: CERAMIC-100UF-6.3V-20%-X5R_1206_; C1206; MPN GRM31CR60J107ME39L
C2, C7: 10uF_6.3V_0402_302010053; C0402
C3, C4, C5, C6: 1uF_6.3V_0402_302010003; C0402
D1, D2: SS24FL; SOD-123; MPN B5819W
D3: LED-SMD-RED-DIFFUSED_0603_; LED-0603; MPN 19-217-R6C-AL1M2VY-3T
IC1: ATSAMD51G_TQFN48; TQFN48_7MM
J2: 3220-10-0300-00-TR; SWD_02x05_1.27mm_SMT
J3, J28: GND; Pin_Header_Straight_1x01_Pitch2.54mm
J4: ~RESET; Pin_Header_Straight_1x01_Pitch2.54mm
J5: D2|A2|LDAC; Pin_Header_Straight_1x01_Pitch2.54mm
J6: AREF; Pin_Header_Straight_1x01_Pitch2.54mm
J7: D19|A19; Pin_Header_Straight_1x01_Pitch2.54mm
J8: D18|A18|RDAC; Pin_Header_Straight_1x01_Pitch2.54mm
J9: D5|A5|TX; Pin_Header_Straight_1x01_Pitch2.54mm
J10: D6|A6|RX; Pin_Header_Straight_1x01_Pitch2.54mm
J11: D3|A3; Pin_Header_Straight_1x01_Pitch2.54mm
J12: D4|A4; Pin_Header_Straight_1x01_Pitch2.54mm
J13: D1|A1; Pin_Header_Straight_1x01_Pitch2.54mm
J14: D14|SDA; Pin_Header_Straight_1x01_Pitch2.54mm
J15: D20|A20; Pin_Header_Straight_1x01_Pitch2.54mm
J16: D15|SCL; Pin_Header_Straight_1x01_Pitch2.54mm
J17: D16; Pin_Header_Straight_1x01_Pitch2.54mm
J18: D13|SCK; Pin_Header_Straight_1x01_Pitch2.54mm
J19: D17; Pin_Header_Straight_1x01_Pitch2.54mm
J20: D12|MISO; Pin_Header_Straight_1x01_Pitch2.54mm
J21: VBUS; Pin_Header_Straight_1x01_Pitch2.54mm
J22: D11|MOSI; Pin_Header_Straight_1x01_Pitch2.54mm
J23: D10|COM3; Pin_Header_Straight_1x01_Pitch2.54mm
J24: D9|COM2; Pin_Header_Straight_1x01_Pitch2.54mm
J25: D8|SDA; Pin_Header_Straight_1x01_Pitch2.54mm
J26: D7|SCL; Pin_Header_Straight_1x01_Pitch2.54mm
J27: VBAT; Pin_Header_Straight_1x01_Pitch2.54mm
J29, J30: 3.3V; Pin_Header_Straight_1x01_Pitch2.54mm
R1: SMD-RES-100K-1%-1_16W_0402_; R0402; MPN RC0402FR-07100KL
R2: SMD-RES-10K-1%-1_16W_0402_; R0402; MPN RC0402FR-0710KL
R3: SMD-RES-1K-1%-1_16W_0402_; R0402; MPN RC0603JR-072K2L
R4: SMD-RES-0R-5%-1_10W_0603_; R0603; MPN RC0603JR-070RL
R5: SMD-RES-510R-1%-1_10W_0603_; R0603; MPN RC0603FR-07510RL
RGB1, RGB2, RGB3, RGB4, RGB5, RGB6, RGB7, RGB8, RGB9, RGB10, RGB11, RGB12, RGB13, RGB14, RGB15, RGB16, RGB17, RGB18, RGB19, RGB20, RGB21, RGB22, RGB23, RGB24, RGB33: LC8822-2020
SJ1: SOLDERJUMPERCLOSED; SOLDERJUMPER_CLOSEDWIRE
SW1: SMD-BUTTON_2P-3.0X2.5X1.2+0.4MM_; SW2-2.6-3.0X2.5X1.2+0.4MM; MPN B3U-1000P-2P-SMD
U1: SN74LVC2T45DCUR; VSSOP-8_2.3x2mm_Pitch0.5mm
U2: GD25x16; USON8
U3: NCP1117ST33T3G; SOT-223
USB1: MICRO-USB-SMD-B-_10118193-0001LF_; MICRO-USB5+6P-SMD-0.65-B; MPN 10118193-0001LF

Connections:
+3V3: C2.1, C3.1, C4.1, C8.1, IC1.6 (VDDA), IC1.17 (VDDIO), IC1.36 (VDDIO), IC1.44 (VDDIO), J2.1, J29.1, J30.1, R1.1, R2.2, R3.2, RGB33.1 (VDD), SJ1.1, U1.8 (VCCB), U2.8 (VCC), U3.2 (OUT)
/AREF: C5.1, IC1.4 (PA03/I3/VREFA/AIN1), J6.1, SJ1.2
/D+: IC1.34 (PA25/I9/SERCOM3+5.3/D+), USB1.3 (DP)
/D-: IC1.33 (PA24/I8/SERCOM3+5.2/D-), USB1.2 (DM)
/LED_STRIP_CLK: IC1.21 (PA12/I12/I2C/SERCOM2.0+4.1), U1.7 (1B)
/LED_STRIP_DATA: IC1.22 (PA13/I13/I2C/SERCOM2.1+4.0), U1.6 (2B)
/QSPI_CS: IC1.20 (PB11/I11/SERCOM4.3/I2SFS1), R1.2, R4.1
/QSPI_DATA[0]: IC1.13 (PA08/I2C/AIN8/SERCOM0.0+2.1/I2SMCK), U2.5 (MOSI)
/QSPI_DATA[1]: IC1.14 (PA09/I2C/I9/AIN9/SERCOM0.1+2.0/I2SFS0), U2.2 (MISO)
/QSPI_DATA[2]: IC1.15 (PA10/I10/AIN10/SERCOM0+2.2/I2SCK), U2.3 (WP#/IO2)
/QSPI_DATA[3]: IC1.16 (PA11/I11/AIN11/SERCOM0+2.3/I2SDO), U2.7 (HOLD#/IO3)
/QSPI_SCK: IC1.19 (PB10/I10/SERCOM4.2/I2SDI), U2.6 (SCK)
/STATUS_LED_CLK: IC1.1 (PA00/EINT0/SERCOM1.0), RGB33.5 (CI)
/STATUS_LED_DATA: IC1.2 (PA01/EINT1/SERCOM1.1), RGB33.6 (DI)
/SWCLK: IC1.45 (PA30/I14/SECOM1.2/SWCLK), J2.4, R3.1
/SWDIO: IC1.46 (PA31/I15/SECOM1.3/SWDIO), J2.2
/VHI: C1.1, C9.1, C10.1, D1.2 (-), D2.2 (-), RGB1.1 (VDD), RGB2.1 (VDD), RGB3.1 (VDD), RGB4.1 (VDD), RGB5.1 (VDD), RGB6.1 (VDD), RGB7.1 (VDD), RGB8.1 (VDD), RGB9.1 (VDD), RGB10.1 (VDD), RGB11.1 (VDD), RGB12.1 (VDD), RGB13.1 (VDD), RGB14.1 (VDD), RGB15.1 (VDD), RGB16.1 (VDD), RGB17.1 (VDD), RGB18.1 (VDD), RGB19.1 (VDD), RGB20.1 (VDD), RGB21.1 (VDD), RGB22.1 (VDD), RGB23.1 (VDD), RGB24.1 (VDD), U1.1 (VCCA), U3.3 (IN)
/~RESET: C6.1, IC1.40 (/RESET), J2.10, J4.1, R2.1, SW1.1
GND: C1.2, C2.2, C3.2, C4.2, C5.2, C6.2, C7.2, C8.2, C9.2, C10.2, D3.2 (-), IC1.5 (GNDA), IC1.18 (GND), IC1.35 (GND), IC1.42 (GND), IC1.THERMAL (TP), J2.3, J2.5, J3.1, J28.1, RGB1.4 (GND), RGB2.4 (GND), RGB3.4 (GND), RGB4.4 (GND), RGB5.4 (GND), RGB6.4 (GND), RGB7.4 (GND), RGB8.4 (GND), RGB9.4 (GND), RGB10.4 (GND), RGB11.4 (GND), RGB12.4 (GND), RGB13.4 (GND), RGB14.4 (GND), RGB15.4 (GND), RGB16.4 (GND), RGB17.4 (GND), RGB18.4 (GND), RGB19.4 (GND), RGB20.4 (GND), RGB21.4 (GND), RGB22.4 (GND), RGB23.4 (GND), RGB24.4 (GND), RGB33.4 (GND), SW1.2, U1.4 (GND), U1.5 (DIR), U2.4 (VSS), U3.1 (GND), USB1.5 (GND), USB1.6 (GND), USB1.7 (GND), USB1.8 (GND), USB1.9 (GND), USB1.10 (GND), USB1.11 (GND)
unnamed: C7.1, IC1.41 (VDDCORE)
unnamed: D3.1 (+), R5.2
unnamed: IC1.3 (PA02/EINT2/AIN0/VOUT0), J5.1
unnamed: IC1.7 (PB08/I8/AIN2/SERCOM4.0), J13.1
unnamed: IC1.8 (PB09/I9/AIN3/SERCOM4.1), J15.1
unnamed: IC1.9 (PA04/I4/VREFB/AIN4/SERCOM0.0), J7.1
unnamed: IC1.10 (PA05/I5/AIN5/VOUT1/SERCOM0.1), J8.1
unnamed: IC1.11 (PA06/I6/VREFC/AIN6/SERCOM0.2), J9.1
unnamed: IC1.12 (PA07/I7/AIN7/SERCOM0.3), J10.1
unnamed: IC1.23 (PA14/I14/SERCOM2+4.2), J14.1
unnamed: IC1.24 (PA15/I15/SERCOM2+4.3), J16.1
unnamed: IC1.25 (PA16/I2C/I0/SERCOM1.0+3.1), J17.1
unnamed: IC1.26 (PA17/I2C/I1/SERCOM1.1+3.0), J18.1
unnamed: IC1.27 (PA18/I2/SERCOM1+3.2), J20.1
unnamed: IC1.28 (PA19/I3/SERCOM1+3.3), J22.1
unnamed: IC1.29 (PA20/I4/SERCOM3+5.2/I2SFS0), J23.1
unnamed: IC1.30 (PA21/I5/SERCOM3+5.3/I2SDO), J24.1
unnamed: IC1.31 (PA22/I2C/I6/SERCOM3.0+5.1/I2SDI), J25.1
unnamed: IC1.32 (PA23/I2C/I7/SERCOM3.1+5.0/SOF/I2SFS1), J26.1
unnamed: IC1.37 (PB22/I6/SERCOM1+5.2), J19.1
unnamed: IC1.38 (PB23/I7/SERCOM1+5.3), R5.1
unnamed: IC1.47 (PB02/I2/AIN14/SERCOM5.0), J11.1
unnamed: IC1.48 (PB03/I3/AIN15/SERCOM5.1), J12.1
unnamed: R4.2, U2.1 (SSEL)
unnamed: RGB1.2 (CO), RGB2.5 (CI)
unnamed: RGB1.3 (DO), RGB2.6 (DI)
unnamed: RGB1.5 (CI), U1.2 (1A)
unnamed: RGB1.6 (DI), U1.3 (2A)
unnamed: RGB2.2 (CO), RGB3.5 (CI)
unnamed: RGB2.3 (DO), RGB3.6 (DI)
unnamed: RGB3.2 (CO), RGB4.5 (CI)
unnamed: RGB3.3 (DO), RGB4.6 (DI)
unnamed: RGB4.2 (CO), RGB5.5 (CI)
unnamed: RGB4.3 (DO), RGB5.6 (DI)
unnamed: RGB5.2 (CO), RGB6.5 (CI)
unnamed: RGB5.3 (DO), RGB6.6 (DI)
unnamed: RGB6.2 (CO), RGB7.5 (CI)
unnamed: RGB6.3 (DO), RGB7.6 (DI)
unnamed: RGB7.2 (CO), RGB8.5 (CI)
unnamed: RGB7.3 (DO), RGB8.6 (DI)
unnamed: RGB8.2 (CO), RGB9.5 (CI)
unnamed: RGB8.3 (DO), RGB9.6 (DI)
unnamed: RGB10.2 (CO), RGB11.5 (CI)
unnamed: RGB10.3 (DO), RGB11.6 (DI)
unnamed: RGB9.2 (CO), RGB10.5 (CI)
unnamed: RGB9.3 (DO), RGB10.6 (DI)
unnamed: RGB11.2 (CO), RGB12.5 (CI)
unnamed: RGB11.3 (DO), RGB12.6 (DI)
unnamed: RGB12.2 (CO), RGB13.5 (CI)
unnamed: RGB12.3 (DO), RGB13.6 (DI)
unnamed: RGB13.2 (CO), RGB14.5 (CI)
unnamed: RGB13.3 (DO), RGB14.6 (DI)
unnamed: RGB14.2 (CO), RGB15.5 (CI)
unnamed: RGB14.3 (DO), RGB15.6 (DI)
unnamed: RGB15.2 (CO), RGB16.5 (CI)
unnamed: RGB15.3 (DO), RGB16.6 (DI)
unnamed: RGB16.2 (CO), RGB17.5 (CI)
unnamed: RGB16.3 (DO), RGB17.6 (DI)
unnamed: RGB17.2 (CO), RGB18.5 (CI)
unnamed: RGB17.3 (DO), RGB18.6 (DI)
unnamed: RGB18.2 (CO), RGB19.5 (CI)
unnamed: RGB18.3 (DO), RGB19.6 (DI)
unnamed: RGB19.2 (CO), RGB20.5 (CI)
unnamed: RGB19.3 (DO), RGB20.6 (DI)
unnamed: RGB20.2 (CO), RGB21.5 (CI)
unnamed: RGB20.3 (DO), RGB21.6 (DI)
unnamed: RGB21.2 (CO), RGB22.5 (CI)
unnamed: RGB21.3 (DO), RGB22.6 (DI)
unnamed: RGB22.2 (CO), RGB23.5 (CI)
unnamed: RGB22.3 (DO), RGB23.6 (DI)
unnamed: RGB23.2 (CO), RGB24.5 (CI)
unnamed: RGB23.3 (DO), RGB24.6 (DI)
VBAT: D2.1 (+), J27.1
VBUS: D1.1 (+), J21.1, USB1.1 (VCC)
VSW: IC1.43 (VSW)

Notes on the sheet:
RESET
SERCOM0: TX/RX SERCOM1: STATUS LED SERCOM2: LED STRIP SERCOM3: SPI SERCOM4: I2C SERCOM5: UNUSED
Title: M4-Breadstick Designer: Michael Rangen Company: Breadstick Innovations Date: Aug 3, 2021 Forked From: Adafruit ItsyBitsy M4 Express

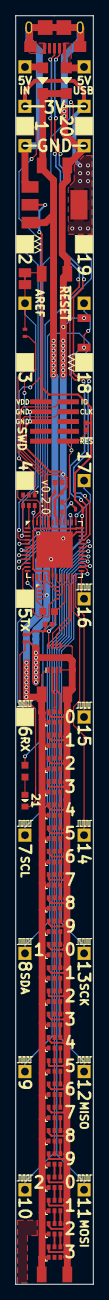
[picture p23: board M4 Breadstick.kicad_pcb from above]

Board: 4 copper layers, 10.0 x 163.6 mm, 79 parts (0 on the bottom side), 93 nets.

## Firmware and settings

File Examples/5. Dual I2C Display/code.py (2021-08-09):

#Dual I2C Display Example

# Modified Circuit Python Firmware Required #
# https://github.com/adafruit/circuitpython/issues/1760#issuecomment-570802884
# I added #define CIRCUITPY_DISPLAY_LIMIT (2) to circuitpython/py/mpconfigboard.h
# and recompiled the firware in order to allow more than 1 display bus.

#Display Info
#SSD1306
#128x64
#0x3C & 0x3D

#I2C Bus On Right Hand Bus Rails
#D16/SCL/PA16/SERCOM3.1
#D13/SDA/PA17/SERCOM3.0

#SERCOM pads are extremely flexible, excluding I2C protocol
#SDA must be on Pad-0 of a SERCOM
#SCL must be on Pad-1 of a SERCOM

import board
import displayio
import terminalio
from adafruit_display_text import label
import adafruit_displayio_ssd1306
from time import sleep
import busio
import analogio

#ALWAYS INCLUDE LINE TO RELEASE DISPLAYS AT BEGINNING
displayio.release_displays()


I2C_PINS = busio.I2C(board.D16, board.D13)
WIDTH = 128
HEIGHT = 64
ADDRESS_1 = 0x3C
ADDRESS_2 = 0x3D

# Display 1
###############################
#Create Display Bus
display_bus1 = displayio.I2CDisplay(I2C_PINS, device_address=ADDRESS_1)
#Create Display
display1 = adafruit_displayio_ssd1306.SSD1306(display_bus1, width=WIDTH, height=HEIGHT, rotation = 0)
# Make a display group and display it
group1 = displayio.Group(max_size=10, scale=2)
display1.show(group1)
# Make background and add it to the display group1, in position group1[0]
background_bitmap = displayio.Bitmap(WIDTH, HEIGHT, 1)
background_palette = displayio.Palette(1)
background_palette [0] = 0x000000
background = displayio.TileGrid(background_bitmap, pixel_shader=background_palette, x=0, y=0)
group1.append(background)
# Make a text label and add it to the display group1, in position group1[1], ontop of group1[0]
text_label1 = label.Label(terminalio.FONT, text=' '*20, color=0xFFFFFF)
text_label1.anchor_point = (0.0, 0.0) #Set Anchor To Top Left
text_label1.anchored_position = (0,0) #Move Text, Relative To Anchor
group1.append(text_label1)


# Display 2
###############################
#Create Display Bus
display_bus2 = displayio.I2CDisplay(I2C_PINS, device_address=ADDRESS_2)
#Create Display
display2 = adafruit_displayio_ssd1306.SSD1306(display_bus2, width=WIDTH, height=HEIGHT, rotation = 0)
# Make a display group and display it
group2 = displayio.Group(max_size=10, scale=2)
display2.show(group2)
# Make background and add it to the display group2, in position group2[0]
background2 = displayio.TileGrid(background_bitmap, pixel_shader=background_palette, x=0, y=0)
group2.append(background2)
# Make a text label and add it to the display group1, in position group1[1], ontop of group1[0]
text_label2 = label.Label(terminalio.FONT, text=' '*20, color=0xFFFFFF)
text_label2.anchor_point = (0.0, 0.0) #Set Anchor To Top Left
text_label2.anchored_position = (0,0) #Move Text, Relative To Anchor
group2.append(text_label2)


#Potentiometers
pot1 = analogio.AnalogIn(board.A1)
pot2 = analogio.AnalogIn(board.A20)

text_label1.text = 'Display 1'
text_label2.text = ''
sleep(2)

text_label1.text = ''
text_label2.text = 'Display 2'
sleep(2)

text_label1.text = hex(ADDRESS_1)
text_label2.text = ''
sleep(2)

text_label1.text = ''
text_label2.text = hex(ADDRESS_2)
sleep(2)

text_label1.text = 'pot1 - A1'
text_label2.text = 'pot2 - A20'
sleep(3)

while True:
    text_label1.text = str(pot1.value)
    text_label2.text = str(pot2.value)
    sleep(0.1)

# If you're wondering why you're getting the 'too many display busses' error, see comment at the top.

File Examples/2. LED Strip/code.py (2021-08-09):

"""CircuitPython Essentials DotStar example"""
import time
import adafruit_dotstar
import board

num_pixels = 24
pixels = adafruit_dotstar.DotStar(board.LEDSTRIP_CLOCK, board.LEDSTRIP_DATA, num_pixels, brightness=0.1, auto_write=False)


def colorwheel(pos):
    # Input a value 0 to 255 to get a color value.
    # The colours are a transition r - g - b - back to r.
    if pos < 0 or pos > 255:
        return (0, 0, 0)
    if pos < 85:
        return (255 - pos * 3, pos * 3, 0)
    if pos < 170:
        pos -= 85
        return (0, 255 - pos * 3, pos * 3)
    pos -= 170
    return (pos * 3, 0, 255 - pos * 3)


def color_fill(color, wait):
    pixels.fill(color)
    pixels.show()
    time.sleep(wait)


def slice_alternating(wait):
    pixels[::2] = [RED] * (num_pixels // 2)
    pixels.show()
    time.sleep(wait)
    pixels[1::2] = [ORANGE] * (num_pixels // 2)
    pixels.show()
    time.sleep(wait)
    pixels[::2] = [YELLOW] * (num_pixels // 2)
    pixels.show()
    time.sleep(wait)
    pixels[1::2] = [GREEN] * (num_pixels // 2)
    pixels.show()
    time.sleep(wait)
    pixels[::2] = [TEAL] * (num_pixels // 2)
    pixels.show()
    time.sleep(wait)
    pixels[1::2] = [CYAN] * (num_pixels // 2)
    pixels.show()
    time.sleep(wait)
    pixels[::2] = [BLUE] * (num_pixels // 2)
    pixels.show()
    time.sleep(wait)
    pixels[1::2] = [PURPLE] * (num_pixels // 2)
    pixels.show()
    time.sleep(wait)
    pixels[::2] = [MAGENTA] * (num_pixels // 2)
    pixels.show()
    time.sleep(wait)
    pixels[1::2] = [WHITE] * (num_pixels // 2)
    pixels.show()
    time.sleep(wait)


def slice_rainbow(wait):
    pixels[::6] = [RED] * (num_pixels // 6)
    pixels.show()
    time.sleep(wait)
    pixels[1::6] = [ORANGE] * (num_pixels // 6)
    pixels.show()
    time.sleep(wait)
    pixels[2::6] = [YELLOW] * (num_pixels // 6)
    pixels.show()
    time.sleep(wait)
    pixels[3::6] = [GREEN] * (num_pixels // 6)
    pixels.show()
    time.sleep(wait)
    pixels[4::6] = [BLUE] * (num_pixels // 6)
    pixels.show()
    time.sleep(wait)
    pixels[5::6] = [PURPLE] * (num_pixels // 6)
    pixels.show()
    time.sleep(wait)


def rainbow_cycle(wait):
    for j in range(255):
        for i in range(num_pixels):
            rc_index = (i * 256 // num_pixels) + j
            pixels[i] = colorwheel(rc_index & 255)
        pixels.show()
        time.sleep(wait)


RED = (255, 0, 0)
YELLOW = (255, 150, 0)
ORANGE = (255, 40, 0)
GREEN = (0, 255, 0)
TEAL = (0, 255, 120)
CYAN = (0, 255, 255)
BLUE = (0, 0, 255)
PURPLE = (180, 0, 255)
MAGENTA = (255, 0, 20)
WHITE = (255, 255, 255)

while True:


    # Increase this number to slow down the rainbow animation.
    rainbow_cycle(0.01)

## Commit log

2021-08-09 Cleared ItsyBitsy M4-Express Files
    [Adafruit ItsyBitsy M4.brd, Adafruit ItsyBitsy M4.sch]
2021-08-09 Added Design Files and Documentation
    [ItsyBitsy M4 Express SAMD51G19A PINOUT.xlsx, M4 Breadstick SAMD51G19A PINOUT.xlsx, M4 Breadstick.kicad_pcb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]
2021-11-07 Multi sheets created
    [LEDs.sch, M4 Breadstick.sch, Power.sch]
2021-11-07 LEDs moved to child sheet
    [LEDs.sch, M4 Breadstick.sch]
2021-11-07 page template done
    needs review from mike
    [LEDs.sch, M4 Breadstick.sch, Power.sch]
